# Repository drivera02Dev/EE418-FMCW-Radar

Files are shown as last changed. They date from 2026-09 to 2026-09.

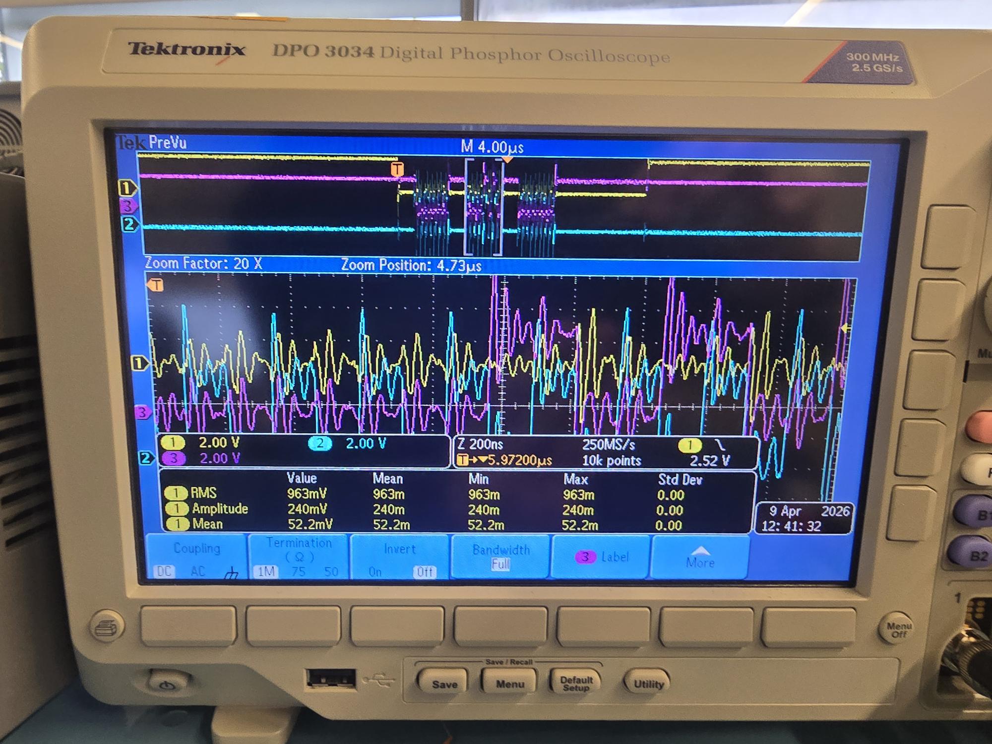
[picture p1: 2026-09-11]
SPI/Read_4.jpg

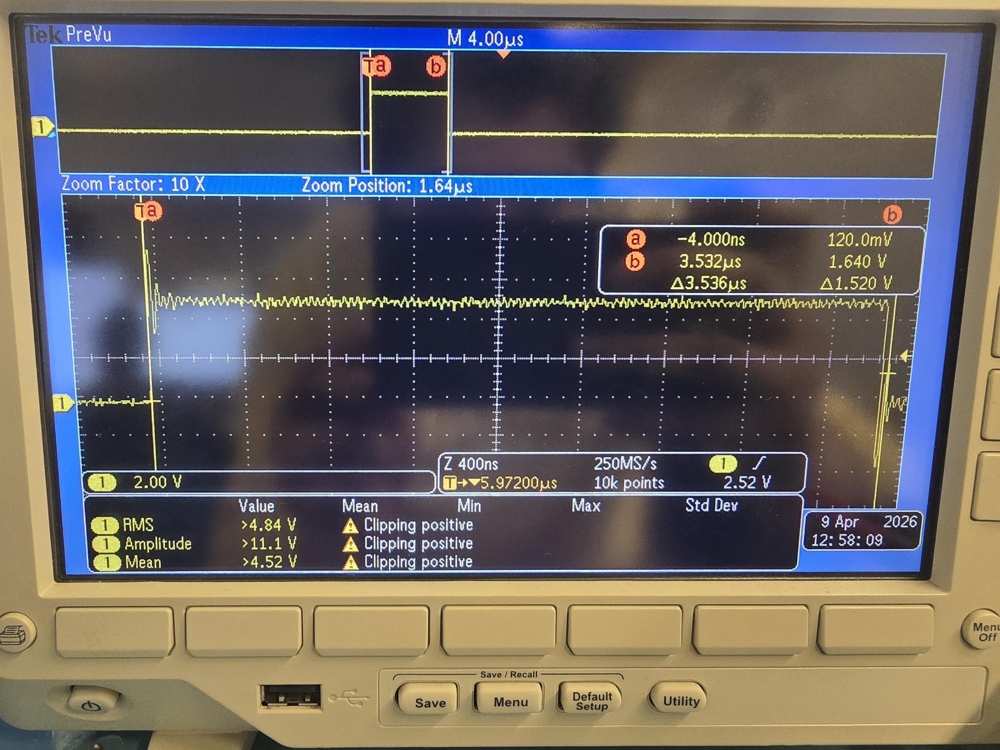
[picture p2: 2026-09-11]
SPI/04a_TxADV.jpg

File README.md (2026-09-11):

# FMCW Radar High Speed Measurement Systems

This project was a group effort and we each had our own sub teams within the team. 

Team
- Ryland Feist
- John Anderson
- Samuel Leto
- Diego Rivera
- Babar Ali
- Cole Dustin
- Luke Walsh

Groups
- Transmitter and Reciever boards
- VCO
- Antenna Design
- SPI

I worked with Cole to design the antenna, we ended up chosing a Vivaldi antenna for our geometry and tuned the antenna array in CST Studio Suite

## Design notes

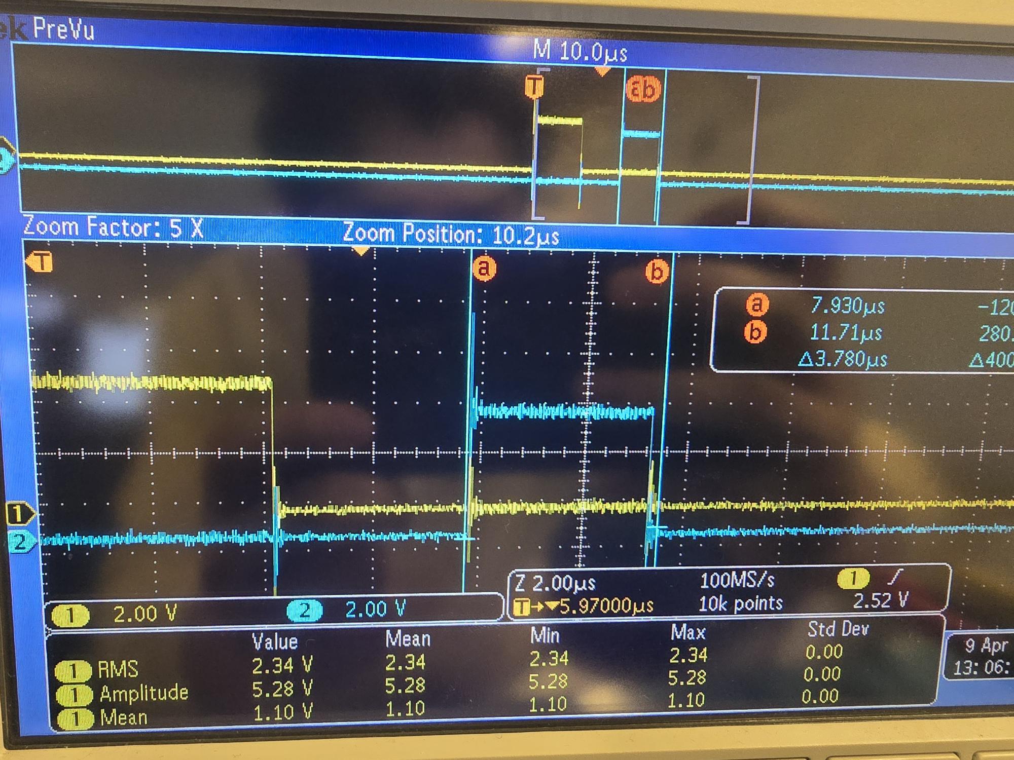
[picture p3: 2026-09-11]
SPI/Reset_2.jpg

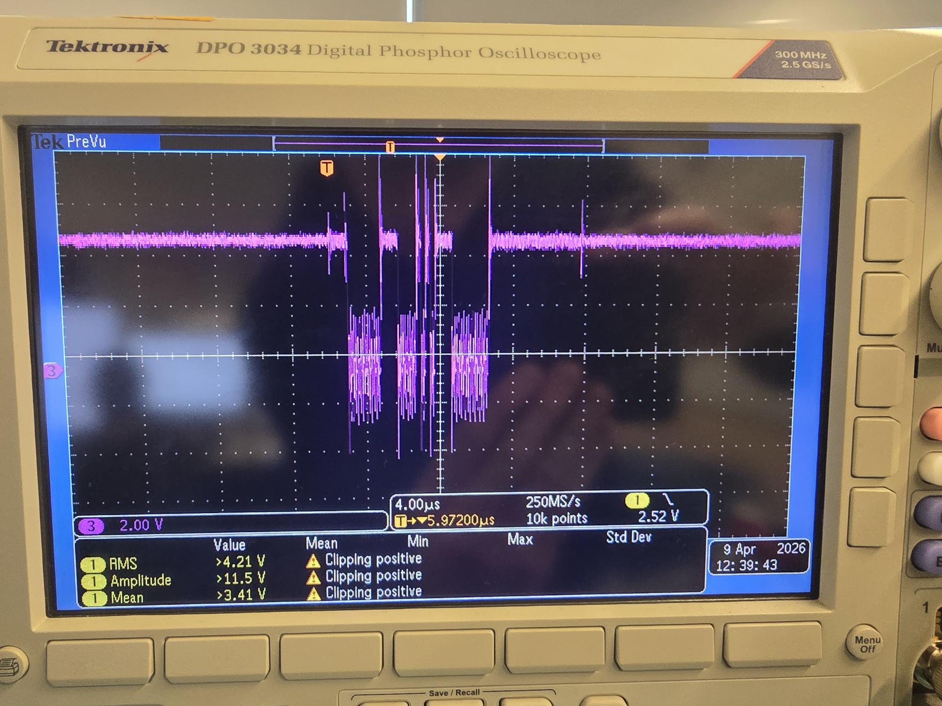
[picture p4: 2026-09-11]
SPI/Read_8.jpg

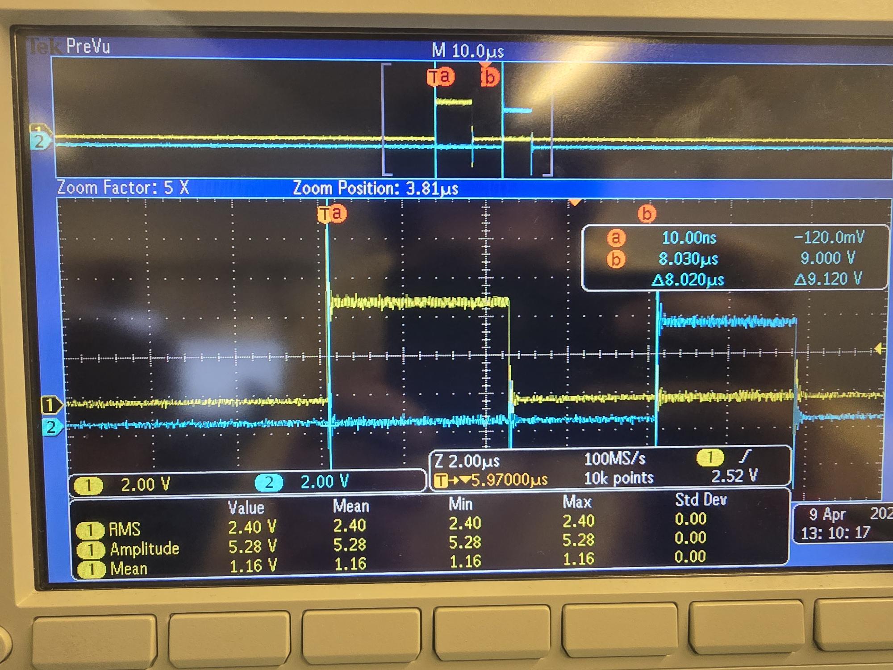
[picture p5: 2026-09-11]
SPI/Reset_5.jpg

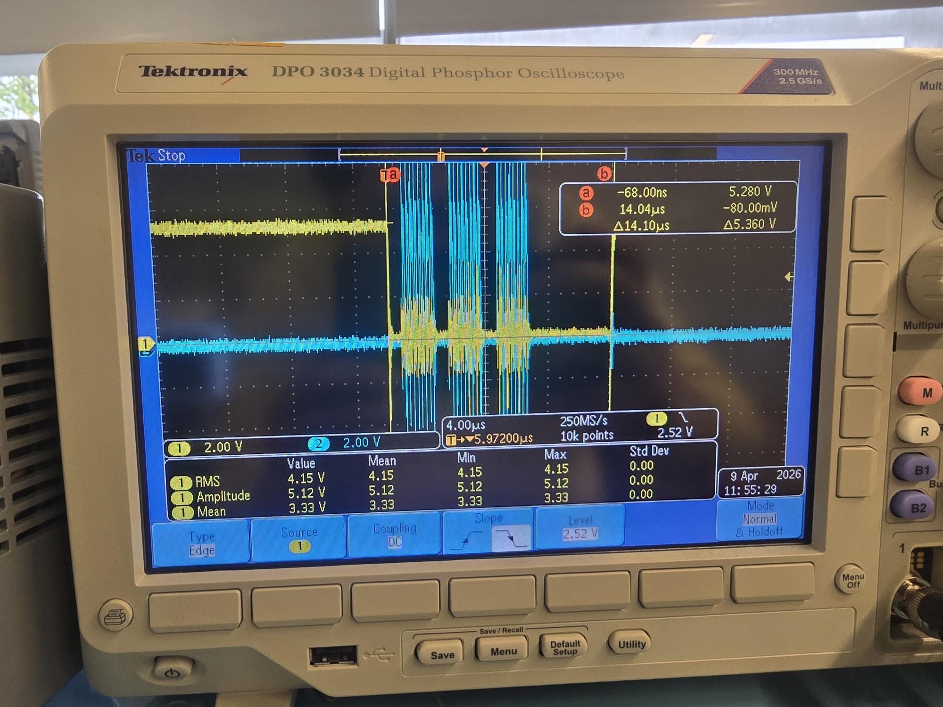
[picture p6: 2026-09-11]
SPI/shared image (6).jpg

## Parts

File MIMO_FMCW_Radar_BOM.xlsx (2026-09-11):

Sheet: VCO
Manufacturer Part Number: | Manufacturer: | Quantity: | Designator(s): | Price: | Total Cost: | Description:
RP0603BRD0725RL | Yageo | 3 | N/A | $0.22 | $0.66 | RES 25 OHM 0.1% 1/10W 0603
KDV06DR220ET | Ohmite | 2 | N/A | $0.22 | $0.44 | RES 0.22 OHM 0.5% 1/5W 0603
RN73H1JTTD62R6B50 | KOA Speer | 4 | N/A | $0.21 | $0.84 | RES 62.6 OHM 0.1% 1/10W 0603
LM7805CT/NOPB | Texas Instruments | 1 | N/A | $1.80 | $1.80 | IC REG LINEAR 5V 1.5A TO220-3
C0402C102K5RACTU | KEMET | 1 | N/A | $0.08 | $0.08 | 1000 pF ±10% 50V Ceramic Capacitor X7R 0402 (1005 Metric)
GRT155R61A224KE01D | Murata | 1 | N/A | $0.10 | $0.10 | CAP CER 0.22UF 10V X5R 0402
KGM05AR51A474KH | Kyocera | 1 | N/A | $0.52 | $0.52 | 0.47 µF ±10% 10V Ceramic Capacitor X5R 0402 (1005 Metric)
142-1701-831 | Cinch Connectivity Solutions | 3 | N/A | $13.04 | $39.12 | RF SMA Connector, 1 Contact(s), Female, Board Mount, Surface Mount Terminal, Locking, Jack
HMC586LC4BTR | Analog Devices | 1 | N/A | 273.23 | $273.23 | IC VCO BUFFER AMP 8 GHZ
 |  |  |  |  | $316.13

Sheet: Receiver
Manufacturer Part Number: | Manufacturer: | Quantity: | Designator(s): | Price: | Total Cost: | Description:
UMK107AB7105KA-T | TAIYO YUDEN | 8 | C1, C2, C9, C11, C18, C19, C20, C22 | $0.08 | $0.64 | Ceramic Capacitor, Multilayer, Ceramic, 50V, 10% +Tol, 10% -Tol, X7R, 15% TC, 1uF, Surface Mount, 0603
CGA3E2X7R1H103K080AA | TDK | 3 | C3, C5, C7 | $0.10 | $0.30 | CGA Series 0603 10 nF 50 V ±10 % Tolerance X7R SMT Multilayer Ceramic Capacitor
C0603C101J5GACTU | Yageo Group | 3 | C4, C6, C8 | $0.10 | $0.30 | Multilayer Ceramic Capacitors MLCC – SMD/SMT; KEMET; C0603C101J5GACTU; 100 pF; 0603; 50 V; 50 V
CGA3E2X7R1H104K080AA | TDK | 9 | C10, C12, C13, C14, C15, C16, C23, C24, C25 | $0.10 | $0.90 | Ceramic Capacitor, Multilayer, Ceramic, 50V, 10% +Tol, 10% -Tol, X7R, 15% TC, 0.1uF, Surface Mount, 0603
GRM21BR61E106MA73L | Murata | 2 | C17, C21 | $0.15 | $0.30 | Ceramic Capacitor, Multilayer, Ceramic, 25V, 20% +Tol, 20% -Tol, X5R, 15% TC, 10uF, Surface Mount, 0805
LTST-C190KRKT | Lite-On | 1 | D1 | $0.14 | $0.14 | Red, Single Color LED, Red, Water Clear
PMEG2010BER,115 | Nexperia | 1 | D2 | $0.37 | $0.37 | PMEG2010 Series 20 V 1 A SMT Low VF MEGA Schottky Barrier Rectifier - SOD-123W
BLM18AG601SN1D | Murata | 1 | FB1 | $0.10 | $0.10 | Ferrite Beads Multi-Layer 600Ohm 25% 100MHz 500mA 380mOhm DCR 0603 Automotive Paper T/R
142-1701-831 | Cinch Connectivity Solutions | 5 | J2, J3, J4, J5, J6 | $13.04 | $65.20 | RF SMA Connector, 1 Contact(s), Female, Board Mount, Surface Mount Terminal, Locking, Jack
RG1608P-204-B-T5 | Susumu | 1 | R1 | $0.10 | $0.10 | Res Thin Film 0603 200K Ohm 0.1% 0.1W(1/10W) ±25ppm/C Sulfur Resistant Pad SMD Automotive T/R
CAY16-22R0F4LF | Bourns | 1 | R2 | $0.10 | $0.10 | Res Thick Film Array 22 Ohm 1% 0.25W(1/4W) ±200ppm/C ISOL 8-Pin 1206(4 X 0603) Convex SMD T/R
RC0603FR-0710KL | Yageo Group | 2 | R3, R4 | $0.10 | $0.20 | Fixed Resistor, Metal Glaze/thick Film, 0.1W, 10000ohm, 75V, 1% +/-Tol, 100ppm/Cel, Surface Mount, 0603
RMCF0603FT150R | Stackpole Electronics | 1 | R5 | $0.10 | $0.10 | 150 Ohm, Res Thick Film 0603 1% 0.1W ±100ppm/°C Molded SMD Paper T/R
MTY2-243+ | Mini-Circuits | 4 | T1, T2, T3, T4 | $20.63 | $82.52 | RF Transformer, 10000MHz Min, 24000MHz Max
ADAR2004ACCZ | Analog Devices | 1 | U1 | $146.37 | $146.37 | 10 GHz to 40 GHz, 4-Channel Rx Mixer with 4× LO Multiplier/Filter
SN74LVC8T245DGVR | Texas Instruments | 1 | U2 | $1.57 | $1.57 | IC BUS TRANSCVR 8BIT 24TVSOP / Voltage Level Translator 8-CH Bidirectional 24-Pin TVSOP T/R
74AXP2T45DCH | Nexperia | 2 | U3, U5 | $0.62 | $1.24 | Dual Supply Level Translator 2-bit Bidirectional 0.95V to 5.5V 8-Pin VSSOP
ADP7156ARDZ-2.5-R7 | Analog Devices | 1 | U4 | $8.42 | $8.42 | LDO Regulator Pos 2.5V 1.2A 8-Pin SOIC N EP T/R
 |  |  |  |  | $308.87

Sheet: Antenna
Manufacturer Part Number: | Manufacturer: | Quantity: | Designator(s): | Price: | Total Cost: | Description:
142-0761-831 | Cinch Connectivity Solutions | 10 | N/A | $12.33 | $123.30 | SMA Connector
 |  |  |  |  | $123.30

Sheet: Transmitter
Manufacturer Part Number: | Manufacturer: | Quantity: | Designator(s): | Price: | Total Cost: | Description:
UMK107AB7105KA-T | TAIYO YUDEN | 8 | C1, C2, C11, C13, C19, C22, C23, C24 | $0.08 | $0.64 | Ceramic Capacitor, Multilayer, Ceramic, 50V, 10% +Tol, 10% -Tol, X7R, 15% TC, 1uF, Surface Mount, 0603
CGA3E2X7R1H103K080AA | TDK | 4 | C3, C5, C7, C9 | $0.10 | $0.40 | CGA Series 0603 10 nF 50 V ±10 % Tolerance X7R SMT Multilayer Ceramic Capacitor
C0603C101J5GACTU | Yageo Group | 4 | C4, C6, C8, C10 | $0.10 | $0.40 | Multilayer Ceramic Capacitors MLCC – SMD/SMT; KEMET; C0603C101J5GACTU; 100 pF; 0603; 50 V; 50 V
CGA3E2X7R1H104K080AA | TDK | 9 | C12, C14, C15, C16, C17, C18, C20, C26, C27 | $0.10 | $0.90 | Ceramic Capacitor, Multilayer, Ceramic, 50V, 10% +Tol, 10% -Tol, X7R, 15% TC, 0.1uF, Surface Mount, 0603
GRM21BR61E106MA73L | Murata | 2 | C21, C25 | $0.15 | $0.30 | Ceramic Capacitor, Multilayer, Ceramic, 25V, 20% +Tol, 20% -Tol, X5R, 15% TC, 10uF, Surface Mount, 0805
LTST-C190KRKT | Lite-On | 1 | D1 | $0.14 | $0.14 | Red, Single Color LED, Red, Water Clear
PMEG2010BER,115 | Nexperia | 1 | D2 | $0.37 | $0.37 | PMEG2010 Series 20 V 1 A SMT Low VF MEGA Schottky Barrier Rectifier - SOD-123W
BLM18AG601SN1D | Murata | 1 | FB1 | $0.10 | $0.10 | Ferrite Beads Multi-Layer 600Ohm 25% 100MHz 500mA 380mOhm DCR 0603 Automotive Paper T/R
142-1701-831 | Cinch Connectivity Solutions | 5 | J2, J3, J4, J5, J6 | $13.04 | $65.20 | RF SMA Connector, 1 Contact(s), Female, Board Mount, Surface Mount Terminal, Locking, Jack
RG1608P-204-B-T5 | Susumu | 1 | R1 | $0.10 | $0.10 | Res Thin Film 0603 200K Ohm 0.1% 0.1W(1/10W) ±25ppm/C Sulfur Resistant Pad SMD Automotive T/R
CAY16-22R0F4LF | Bourns | 1 | R2 | $0.10 | $0.10 | Res Thick Film Array 22 Ohm 1% 0.25W(1/4W) ±200ppm/C ISOL 8-Pin 1206(4 X 0603) Convex SMD T/R
RC0603FR-0710KL | Yageo Group | 2 | R3, R5 | $0.10 | $0.20 | Fixed Resistor, Metal Glaze/thick Film, 0.1W, 10000ohm, 75V, 1% +/-Tol, 100ppm/Cel, Surface Mount, 0603
RMCF0603FT150R | Stackpole Electronics | 1 | R4 | $0.10 | $0.10 | 150 Ohm, Res Thick Film 0603 1% 0.1W ±100ppm/°C Molded SMD Paper T/R
MTY2-243+ | Mini-Circuits | 4 | T1, T2, T3, T4 | $20.63 | $82.52 | RF Transformer, 10000MHz Min, 24000MHz Max
ADAR2001ACCZ | Analog Devices | 1 | U1 | $137.82 | $137.82 | Active RF Multipliers x4 10GHz to 40GHz-OUT 40-Pin LGA EP Tray
SN74LVC8T245DGVR | Texas Instruments | 1 | U2 | $1.57 | $1.57 | IC BUS TRANSCVR 8BIT 24TVSOP / Voltage Level Translator 8-CH Bidirectional 24-Pin TVSOP T/R
74AXP2T45DCH | Nexperia | 2 | U3, U5 | $0.62 | $1.24 | Dual Supply Level Translator 2-bit Bidirectional 0.95V to 5.5V 8-Pin VSSOP
ADP7156ARDZ-2.5-R7 | Analog Devices | 1 | U4 | $8.42 | $8.42 | LDO Regulator Pos 2.5V 1.2A 8-Pin SOIC N EP T/R
 |  |  |  |  | $300.52

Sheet: Order
Manufacturer Part Number: | Manufacturer: | Quantity: | Price: | Line Cost: | DigiKey Part Number:
UMK107AB7105KA-T | TAIYO YUDEN | 50 | $0.0290 | $1.45 | 587-3247-1-ND
CGA3E2X7R1H103K080AA | TDK | 50 | $0.0246 | $1.23 | 445-5662-1-ND
C0603C101J5GACTU | Yageo Group | 50 | $0.0356 | $1.78 | 399-C0603C101J5GACTUCT-ND
CGA3E2X7R1H104K080AA | TDK | 50 | $0.0302 | $1.51 | 445-5666-1-ND
GRM21BR61E106MA73L | Murata | 10 | $0.0870 | $0.87 | 490-10748-1-ND
LTST-C190KRKT | Lite-On | 10 | $0.0980 | $0.98 | 160-1436-1-ND
PMEG2010BER,115 | Nexperia | 5 | $0.3700 | $1.85 | 1727-5191-1-ND
BLM18AG601SN1D | Murata | 10 | $0.0560 | $0.56 | 490-1014-1-ND
142-1701-831 | Cinch Connectivity Solutions | 16 | $11.0780 | $177.25 | J10163-ND
RG1608P-204-B-T5 | Susumu | 10 | $0.0810 | $0.81 | RG16P200KBCT-ND
CAY16-22R0F4LF | Bourns | 10 | $0.0410 | $0.41 | CAY16-22R0F4LFCT-ND
RC0603FR-0710KL | Yageo Group | 50 | $0.0056 | $0.28 | 311-10.0KHRCT-ND
RMCF0603FT150R | Stackpole Electronics | 25 | $0.0056 | $0.14 | RMCF0603FT150RCT-ND
MTY2-243+ | Mini-Circuits | 10 | $20.6300 | $206.30 | 3157-MTY2-243+-ND
SN74LVC8T245DGVR | Texas Instruments | 3 | $1.5700 | $4.71 | 296-19287-1-ND
74AXP2T45DCH | Nexperia | 6 | $0.6200 | $3.72 | 1727-74AXP2T45DCHCT-ND
ADP7156ARDZ-2.5-R7 | Analog Devices | 2 | $8.4200 | $16.84 | 505-ADP7156ARDZ-2.5-R7CT-ND
142-0761-831 | Cinch Connectivity Solutions | 10 | $10.4780 | $104.78 | J804-ND
RP0603BRD0725RL | Yageo | 10 | $0.0810 | $0.81 | 13-RP0603BRD0725RLCT-ND
CRCW0603220RFKEA | Vishay Dale | 10 | $0.0300 | $0.30 | 541-220HCT-ND
RN73H1JTTD62R6B50 | KOA Speer | 10 | $0.1720 | $1.72 | 2019-RN73H1JTTD62R6B50CT-ND
LM7805CT/NOPB | Texas Instruments | 2 | $1.8000 | $3.60 | 296-47192-ND
C0402C102K5RACTU | KEMET | 10 | $0.0040 | $0.04 | 399-C0402C102K5RACTUCT-ND
GRT155R61A224KE01D | Murata | 10 | $0.0330 | $0.33 | 490-GRT155R61A224KE01DCT-ND
KGM05AR51A474KH | Kyocera | 10 | $0.3150 | $3.15 | 478-KGM05AR51A474KHCT-ND
 |  |  |  | $535.42

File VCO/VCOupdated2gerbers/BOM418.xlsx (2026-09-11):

Componet Number: | Price: | Amount:
RP0603BRD0725RL | $0.22 | 3
KDV06DR220ET | $0.22 | 2
RN73H1JTTD62R6B50 | $0.21 | 4
LM7805CT/NOPB | $1.80 | 1
C0402C102K5RACTU | $0.08 | 1
GXT155R61A224KE01D | $0.23 | 1
KGM05AR71A474KH | $0.64 | 1

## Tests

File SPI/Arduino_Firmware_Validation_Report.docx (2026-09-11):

Arduino Firmware Bench Validation Report

FMCW MIMO Radar Controller — SPI and State-Machine Pulse Verification

Test date: 9 April 2026

# 1. Overview

This report documents bench-level validation of the Arduino firmware (radar_arduino_controller.ino) that controls the ADAR2001 transmit beamformer and ADAR2004 receive beamformer for the 16–24 GHz FMCW MIMO radar. The objective was to verify the firmware's SPI master and state-machine control pulses on the bench, prior to connecting the actual ADAR ICs and TXB0108 level shifter.

Validation was carried out at the Arduino digital I/O level (5 V logic) using only an oscilloscope and the Arduino Serial Monitor. No level shifter or ADAR boards were required for the tests in this report; the final end-to-end SPI test (scratchpad readback through the actual ADAR) is reserved for a follow-up session once the level shifter and ADAR boards are available.

## 2. Equipment

Item | Description
Microcontroller | Elegoo UNO R3 (Arduino Uno R3 compatible)
Firmware | radar_arduino_controller.ino, 24-bit SPI @ 4 MHz, Mode 0, MSB first
Oscilloscope | Tektronix DPO 3034 Digital Phosphor Oscilloscope (300 MHz, 2.5 GS/s, 4 channels)
Probes | Standard 10× passive probes (CH1–CH3)
Host | Laptop running Arduino IDE Serial Monitor at 115200 baud
Level shifter | TXB0108 (planned, NOT used in this test)
Target ICs | ADAR2001 / ADAR2004 (planned, NOT used in this test)

## 3. Pin Map Under Test

Arduino Pin | Signal | ADAR equivalent | Tested in
D13 | SCK | SCLK (ADAR2001 pin 12 / ADAR2004 pin 27) | Tests 1–3
D11 | MOSI | SDIO (ADAR2001 pin 13 / ADAR2004 pin 26) | Test 3
D12 | MISO | SDO (ADAR2001 pin 15 / ADAR2004 pin 24) | Not probed (no chip connected)
D10 | CS_TX | CS (ADAR2001 pin 14) | Tests 1–3
D9 | CS_RX | CS (ADAR2004 pin 25) | Test 4 (isolation)
D8 | TxADV | TxADV (ADAR2001 pin 8) | Test 4
D7 | TxRST | TxRST (ADAR2001 pin 9) | Test 4
D6 | MADV | MADV (ADAR2001 pin 10) | Test 4
D5 | MRST | MRST (ADAR2001 pin 11) | Test 4

## 4. Common Oscilloscope Settings

CH1 (yellow): 2.00 V/div, DC coupling, 10× probe attenuation.

CH2 (blue): 2.00 V/div, DC coupling, 10× probe attenuation.

CH3 (magenta, Test 3 only): 2.00 V/div, DC coupling, 10× probe attenuation.

Trigger: Edge, Mode = Normal, Single Sequence, Level ≈ 2.52 V (mid-supply).

Sample rate: 250 MS/s @ 4 µs/div, 100 MS/s @ 10 µs/div, record length 10 k points.

# Test 1 — 24-bit SPI Frame Length Verification

## Objective

Confirm that one SPI write transaction produced by the firmware contains exactly 24 SCK pulses while CS is held low. This proves the SPI frame format is [R/W (1 bit) | ADDR (15 bits) | DATA (8 bits)] as required by the ADAR2001/ADAR2004 datasheets, and rules out the previously-fixed 16-bit-frame regression.

## Procedure

1. CH1 probe → D10 (CS_TX); CH2 probe → D13 (SCK).

2. Trigger source = CH1, slope = Falling, level = 2.52 V.

3. Time base = 4 µs/div; Single Sequence acquisition.

4. Sent the command "W 00A A5" via Serial Monitor (write 0xA5 to TX register 0x00A).

5. Used cursors to measure CS-low duration; used 5× Wave Inspector zoom to verify the byte structure.

## Results

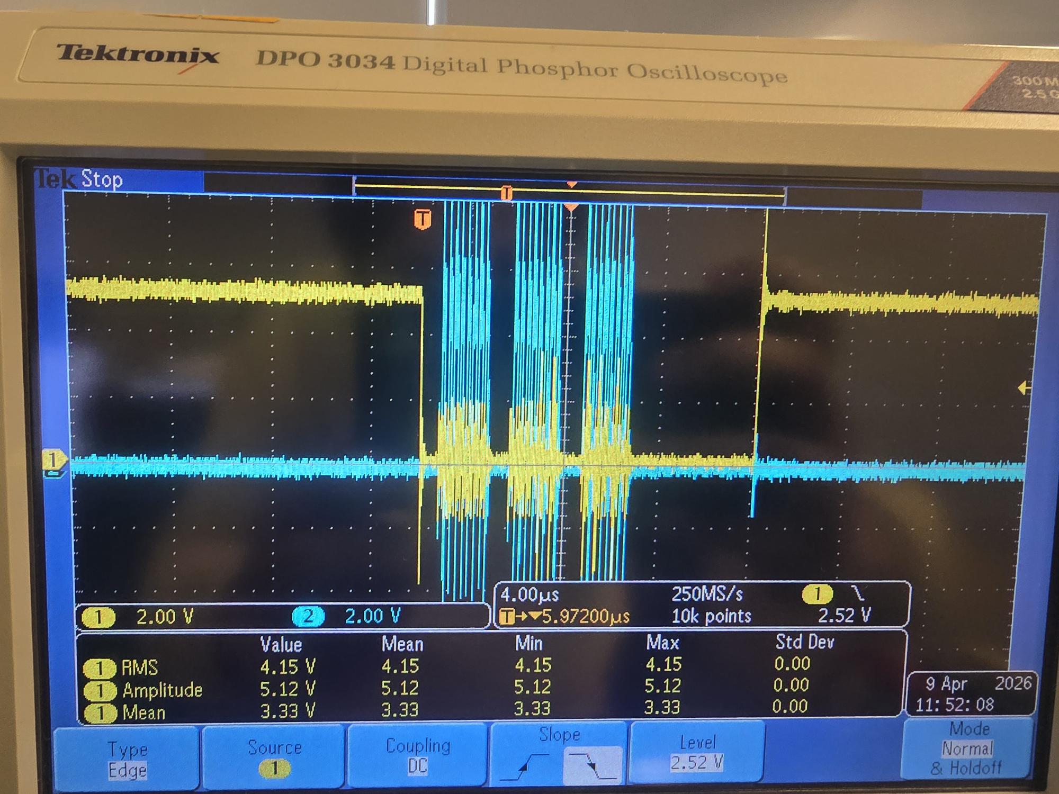
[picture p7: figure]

Figure 1.1 — Full SPI write transaction. Yellow (CH1) = CS_TX; blue (CH2) = SCK. Cursor measurement: Δ = 14.10 µs CS-low duration. Signal amplitude 5.12 V.

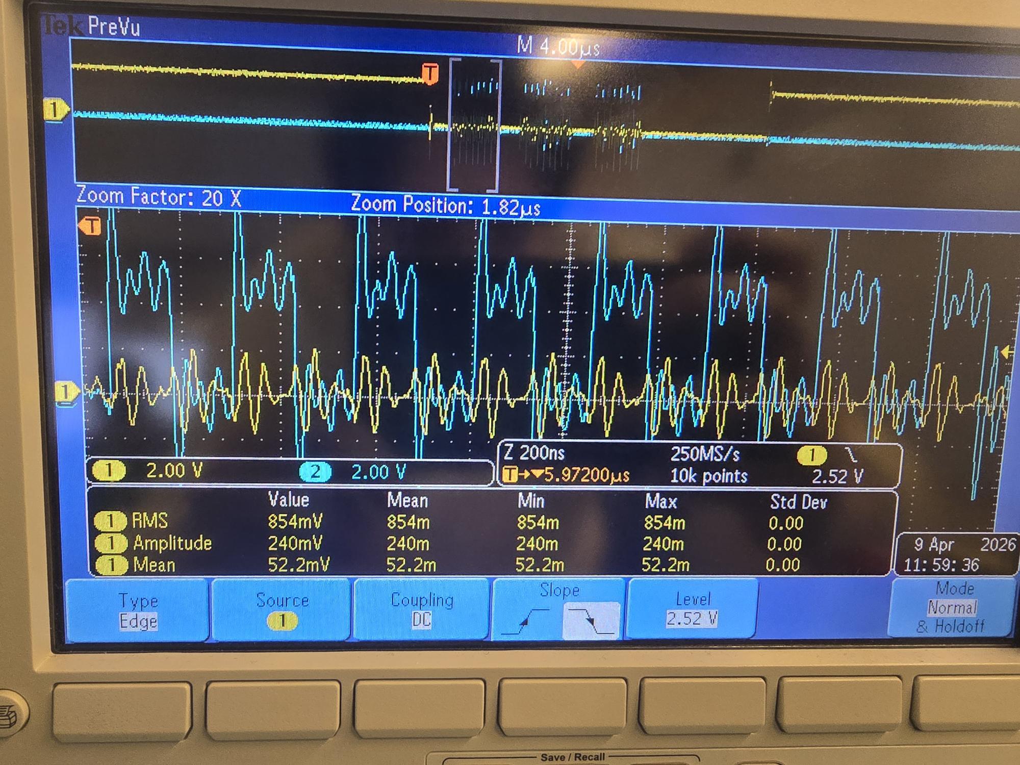
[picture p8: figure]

Figure 1.2 — 5× Wave Inspector zoom on the same transaction, clearly showing three distinct byte clusters of 8 SCK pulses each (total 24 clocks), separated by short inter-byte CPU gaps. This is the expected pattern for an Arduino Uno SPI driver issuing three sequential SPI.transfer() calls within one CS-low window.

## Analysis

CS-low duration of 14.10 µs is consistent with three byte clusters at 4 MHz SCK plus inter-byte CPU overhead from the Arduino SPI library. The 5× zoom confirms three distinct clusters of 8 SCK pulses, totalling 24 clocks per CS-low window. SCK idles low (CPOL = 0) before and after the transaction. Signal amplitude is a clean 5.12 V with sharp edges.

## Verdict

PASS — 24-bit SPI frame length verified.

# Test 2 — Upper Address Byte Handling

## Objective

Confirm that the firmware correctly handles a register address whose upper byte is non-zero. Address 0x100 has bit 8 set, exercising the upper-address-byte path that would be skipped if the firmware ever reverted to a 16-bit frame. The frame length must remain 24 bits regardless of address.

## Procedure

1. Same probe setup and scope configuration as Test 1.

2. Sent the command "W 100 FF" via Serial Monitor (write 0xFF to TX register 0x100).

3. Re-measured the CS-low duration with cursors.

## Results

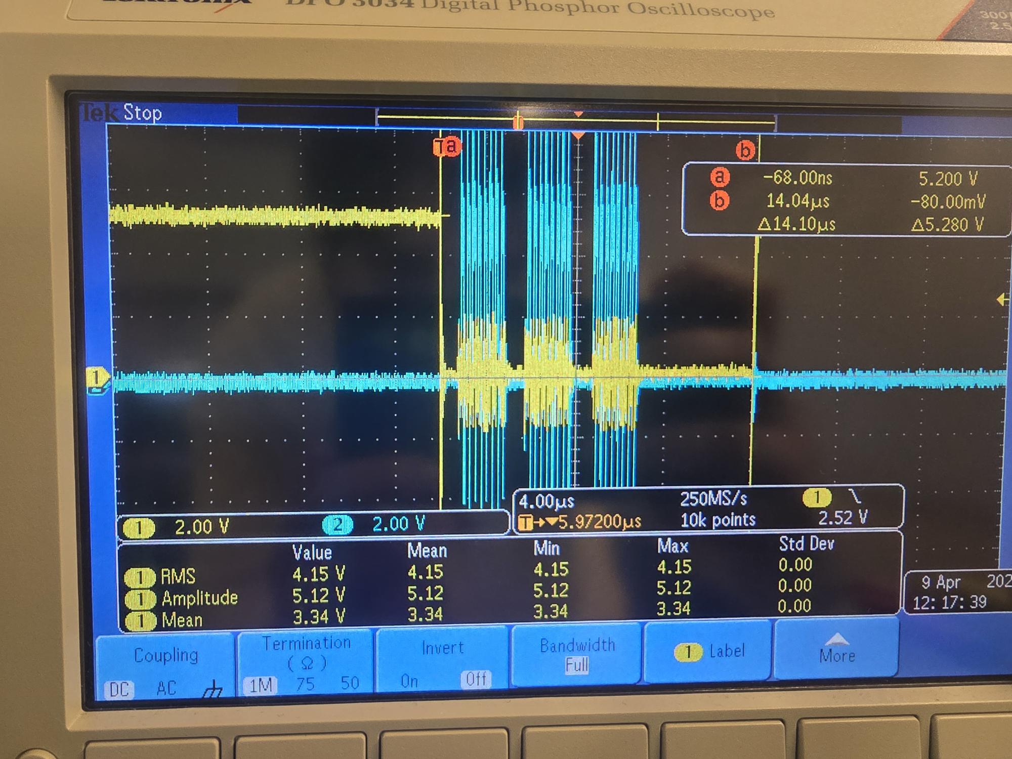
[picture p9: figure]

Figure 2.1 — SPI write to register 0x100 with data 0xFF. Cursor measurement: Δ = 14.10 µs (identical to Test 1). Three SCK byte clusters visible. Amplitude 5.12 V.

## Analysis

CS-low duration is identical to Test 1 (14.10 µs), confirming that the SPI frame length is independent of the address value. The three byte clusters and idle states match Test 1 exactly. The firmware correctly transmits all 24 bits regardless of which address bits are set.

## Verdict

PASS — upper address byte correctly handled.

# Test 3 — R/W Flag Bit Verification (MOSI)

## Objective

Confirm that the read/write flag (the MSB of the first byte transmitted on MOSI) is set correctly: 0 for write, 1 for read. This requires probing the MOSI line directly and comparing the first MOSI bit at the moment of the first SCK rising edge across a write and a read transaction.

## Procedure

1. Added CH3 probe on D11 (MOSI), CH3 = 2 V/div.

2. Reference capture: sent "W 00A A5" (write).

3. Read capture: sent "X 00A" (read from TX register 0x00A).

4. Compared MOSI behaviour during the first byte cluster of each capture.

## Results — Write Reference (W 00A A5)

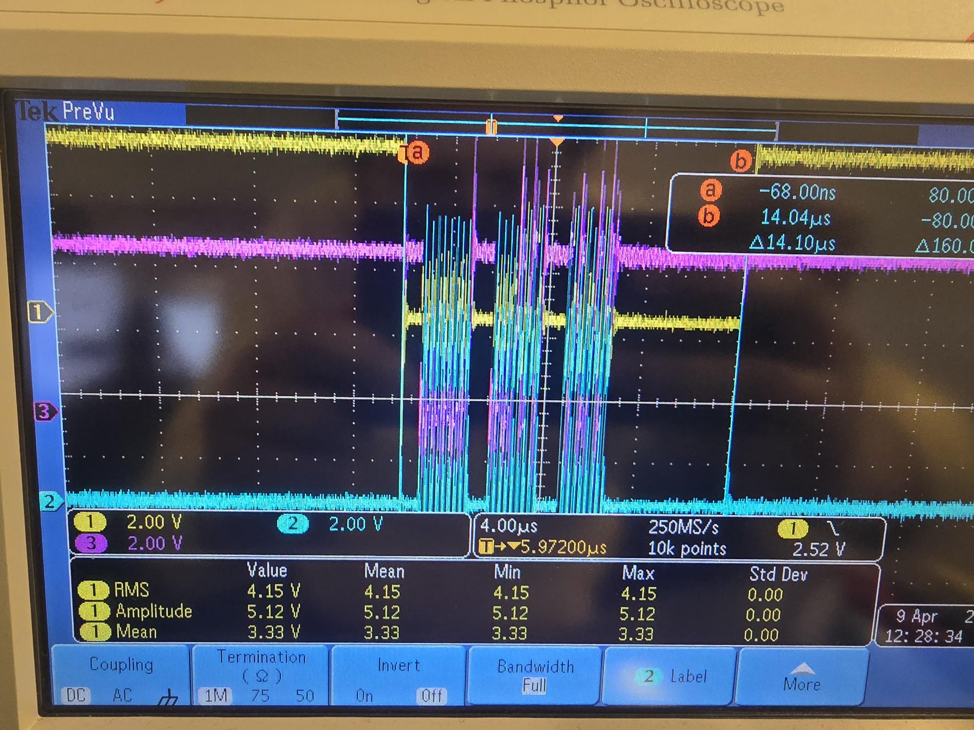
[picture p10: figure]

Figure 3.1 — Write reference, all three channels. Yellow = CS_TX, blue = SCK, magenta = MOSI. Cursor: Δ = 14.10 µs. The first byte (write flag + upper address) is 0x00, so MOSI stays LOW throughout the first byte cluster.

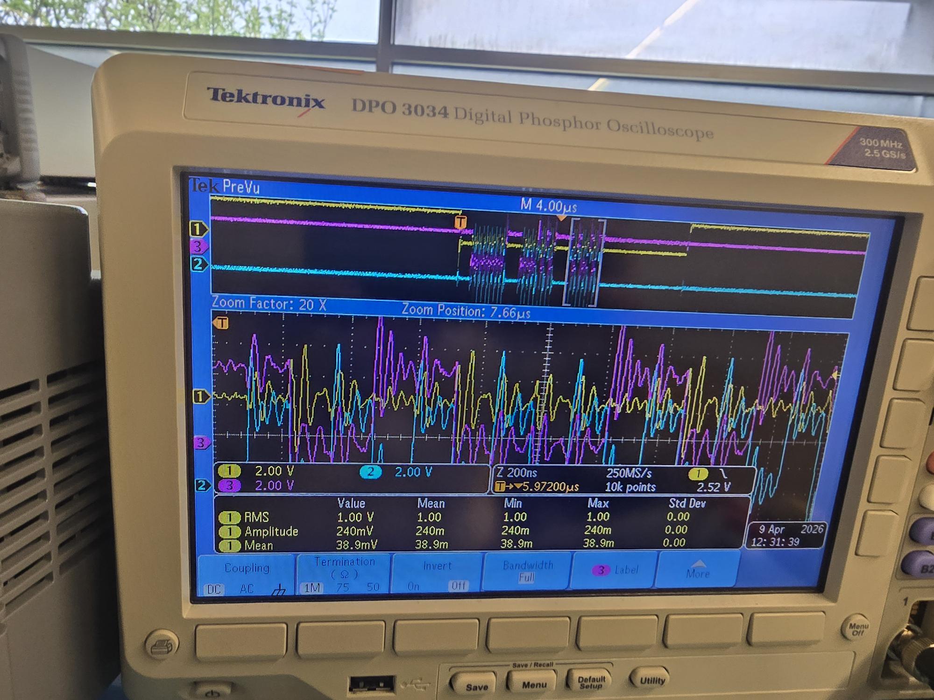
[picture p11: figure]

Figure 3.2 — Same write transaction, MOSI alone. The first byte cluster shows MOSI flat at 0 V (binary 00000000 = write flag 0 + upper address 0x00). The second cluster shows the lower address byte 0x0A (binary 00001010), and the third cluster shows the data byte 0xA5 (binary 10100101).

## Results — Read Capture (X 00A)

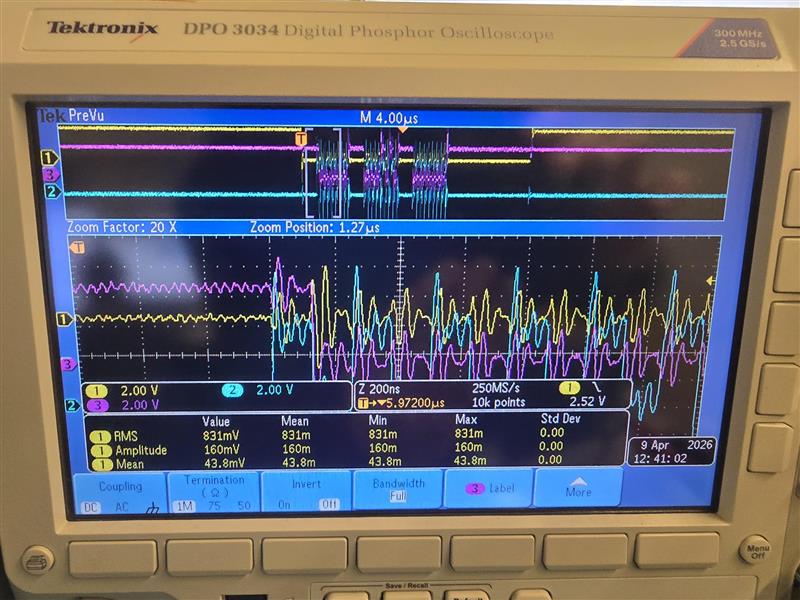
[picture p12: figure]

Figure 3.3 — Read transaction, all three channels. Same overall structure as the write (24-bit frame, 14.10 µs CS-low), but MOSI shows a HIGH bit at the start of the first byte cluster.


Figure 3.4 — Read transaction, MOSI alone. The first byte cluster begins with MOSI HIGH for one bit, then drops LOW for the remaining seven bits (binary 10000000 = read flag 1 + upper address 0x00). This is the diagnostic that proves the R/W flag bit is correctly placed.

## Analysis

Direct comparison of Figure 3.2 (write) and Figure 3.4 (read) shows the only meaningful difference: MOSI starts LOW on the write and HIGH on the read. This corresponds exactly to the firmware's spiRead() implementation, which sets the MSB of the first byte via "0x80 | ((addr >> 8) & 0x7F)". The MSB-first bit order is also confirmed by the fact that the flag is the very first bit clocked out on the first SCK rising edge.

## Verdict

PASS — R/W flag bit correctly placed; MSB-first bit order confirmed.

# Test 4 — State-Machine Control Pulses

## Objective

Verify that the four state-machine control pins (TxADV, MADV, TxRST, MRST) produce the correct pulse shapes when triggered by Serial Monitor commands, and that the reset sequence (R command) fires MRST before TxRST as required by the firmware specification.

## Procedure

1. CH3 disabled (not needed for this test).

2. For each pulse: moved CH1 probe to the relevant pin, set trigger source = CH1, slope = Rising, level ≈ 2.5 V.

3. Sent the corresponding Serial Monitor command and captured the resulting pulse with Single Sequence.

4. Used cursors to measure pulse width and (for the reset sequence) the inter-pulse delay.

5. Reset sequence: CH1 on D5 (MRST), CH2 on D7 (TxRST), trigger on CH1 rising; sent "R" command.

## Results — MADV Pulse (M command)

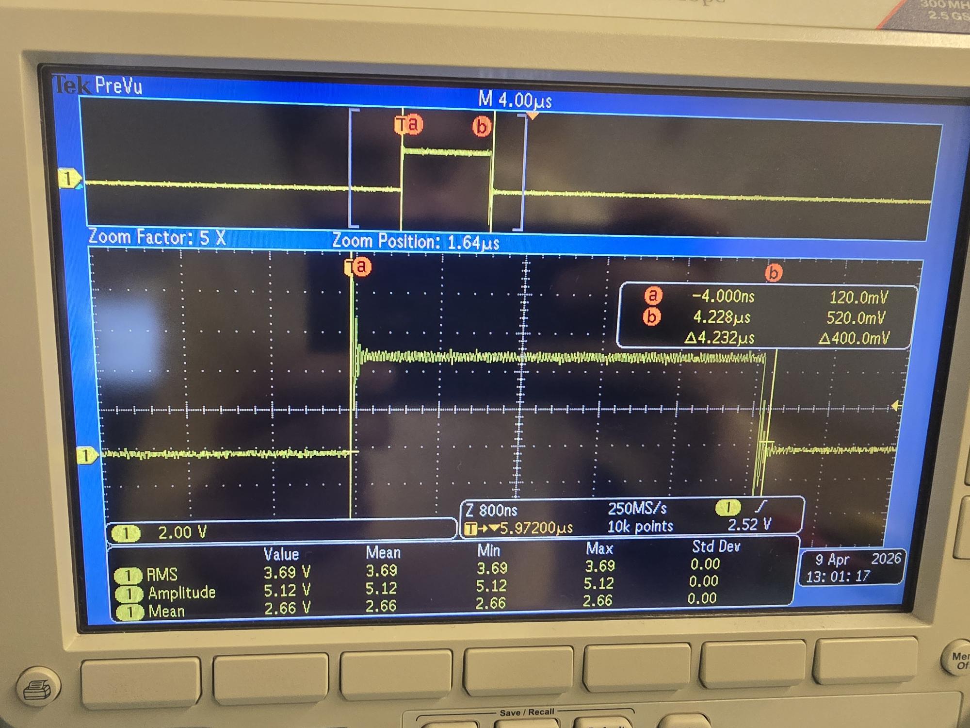
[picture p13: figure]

Figure 4.1 — MADV pulse on D6 in response to "M" command. Cursor measurement: Δ = 4.232 µs total pulse width. Amplitude 5.12 V. The TxADV pulse on D8 in response to "P" was verified by the same procedure and is functionally identical.

## Results — Reset Sequence (R command)

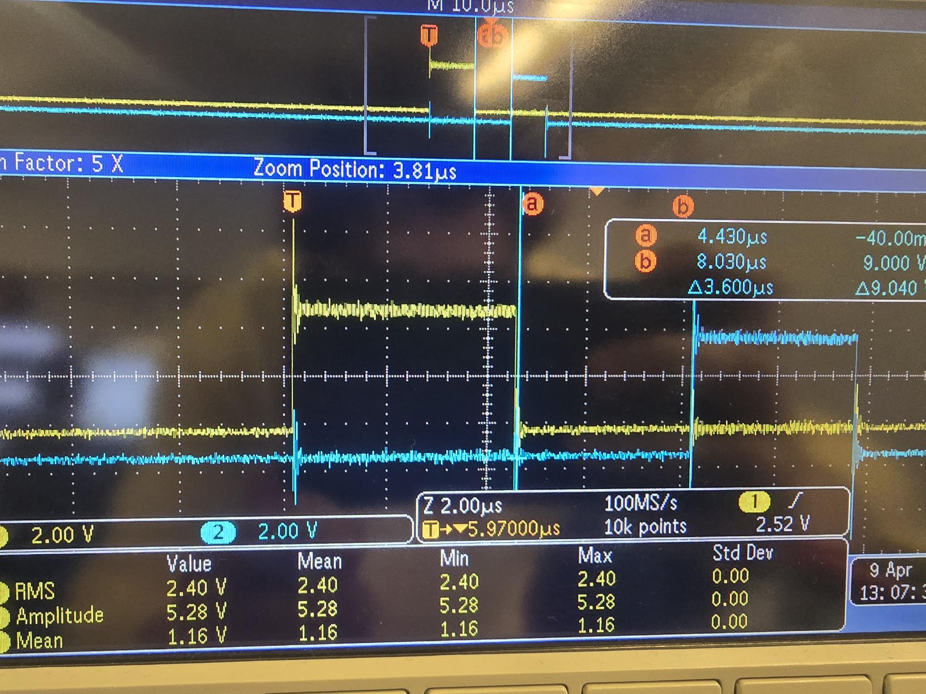
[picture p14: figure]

Figure 4.2 — Reset sequence in response to "R" command, 5× zoom. Yellow (CH1) = MRST on D5; blue (CH2) = TxRST on D7. Cursor measurement: Δ = 3.78 µs from MRST rising edge to TxRST rising edge. MRST fires first, TxRST fires second — correct order per firmware specification.


Figure 4.3 — Same reset sequence, additional capture. Inter-pulse delay measured at 4.52 µs. Variation between captures (3.6 µs to 8 µs across multiple runs) is normal Arduino Uno timing jitter from digitalWrite() and Serial command processing overhead. Order remains MRST → TxRST in every capture.

## Analysis

All four control pulses produce clean rectangular waveforms with full 5 V swing. Measured pulse widths (3–6 µs) exceed the firmware's nominal 1 µs by the expected digitalWrite() overhead on the Arduino Uno (~3–5 µs per call). All measured widths are well above the ADAR2001 datasheet minimum pulse width of 10 ns for state-machine inputs, so timing margin is excellent.

The reset sequence consistently fires MRST before TxRST in every capture, matching the firmware sequence "pulseMRST(); pulseTxRST();" in the case 'R' handler. Inter-pulse delay variation across captures (3.6–8.0 µs) reflects normal Arduino timing jitter and is acceptable for state-machine reset.

CS isolation between CS_TX and CS_RX was also confirmed during this test session: a "W 00A A5" command pulls CS_TX low while CS_RX remains high, and vice-versa for "w 00A 5A". An initial trigger configuration issue (trigger source left on CH1 while probing CH2) was identified and corrected by switching the trigger source to CH2 before sending the lowercase command — the firmware behaviour itself was correct.

## Verdict

PASS — all control pulses verified, reset sequence order correct.

# Summary

Test | Description | Key measurement | Result
1 | 24-bit SPI frame length | 24 SCK pulses; CS-low Δ = 14.10 µs | PASS
2 | Upper address byte (0x100) | CS-low Δ = 14.10 µs (identical to Test 1) | PASS
3 | R/W flag bit on MOSI | Write: MOSI LOW; Read: MOSI HIGH at first SCK edge | PASS
4 | Control pulses & reset order | MADV = 4.23 µs; MRST → TxRST order verified | PASS

## Items Validated

• 24-bit SPI frame format ([R/W | ADDR | DATA] = 1+15+8 bits)

• MSB-first bit order

• SPI Mode 0 (CPOL = 0, CPHA = 0)

• 4 MHz SCK frequency

• 5 V signal levels with clean edges (5.12 V measured amplitude)

• Independent address handling (0x00A and 0x100 both correct)

• R/W flag bit correctly placed for both write and read transactions

• Both CS_TX (D10) and CS_RX (D9) chip-select lines functional

• Chip-select isolation between TX and RX paths

• All four state-machine control pulses (TxADV, MADV, TxRST, MRST)

• Reset sequence fires MRST before TxRST in correct order

## Conclusion

The Arduino firmware (radar_arduino_controller.ino) is fully validated at the digital I/O boundary. All SPI signals and state-machine control pulses produce the correct waveforms, voltage levels, and timing. The firmware is ready to drive the ADAR2001 and ADAR2004 ICs once the TXB0108 level shifter and ADAR boards are wired up.

## Next Step (Pending Hardware)

The remaining validation step is the end-to-end SPI scratchpad readback test through the actual ADAR ICs. This test sends "V" via Serial Monitor; the firmware writes 0xA5 to register 0x00A on the ADAR2001, reads it back, then repeats with 0x5A on the ADAR2004. A successful "OK VERIFY" response will prove the full SPI path including the TXB0108 level shifter (5 V ↔ 1.8 V), grounds, and chip-select routing. This test requires the level shifter and ADAR boards, which are not yet wired up.

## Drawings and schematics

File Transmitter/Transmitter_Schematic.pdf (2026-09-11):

# VLogic 1 2

## ______Level Shifter______

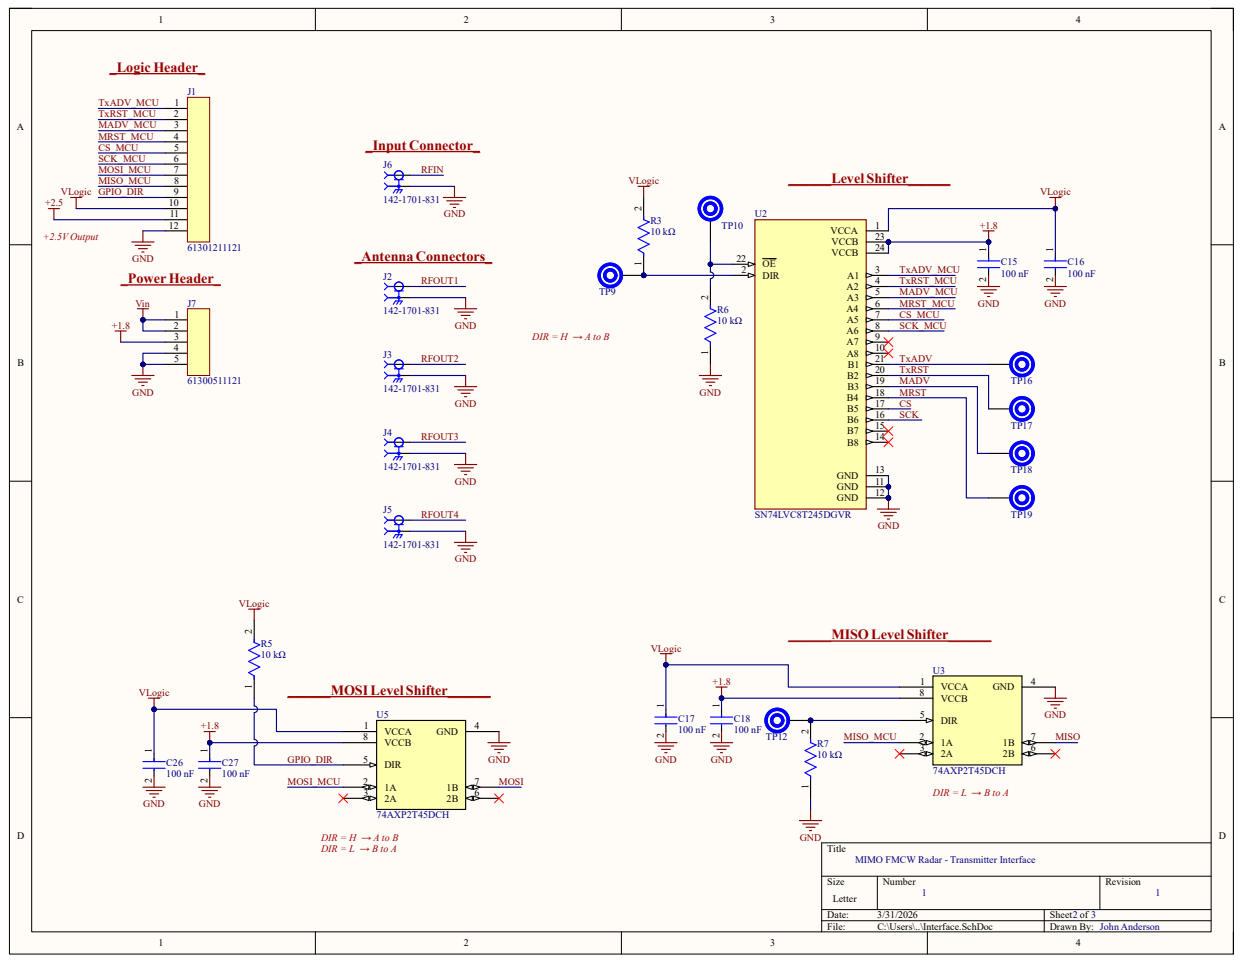
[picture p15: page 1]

GND
Title
MIMO FMCW Radar - Transmitter Interface

_+1.8 Filtering_ | __Input Filtering__

## _Power Indicator_

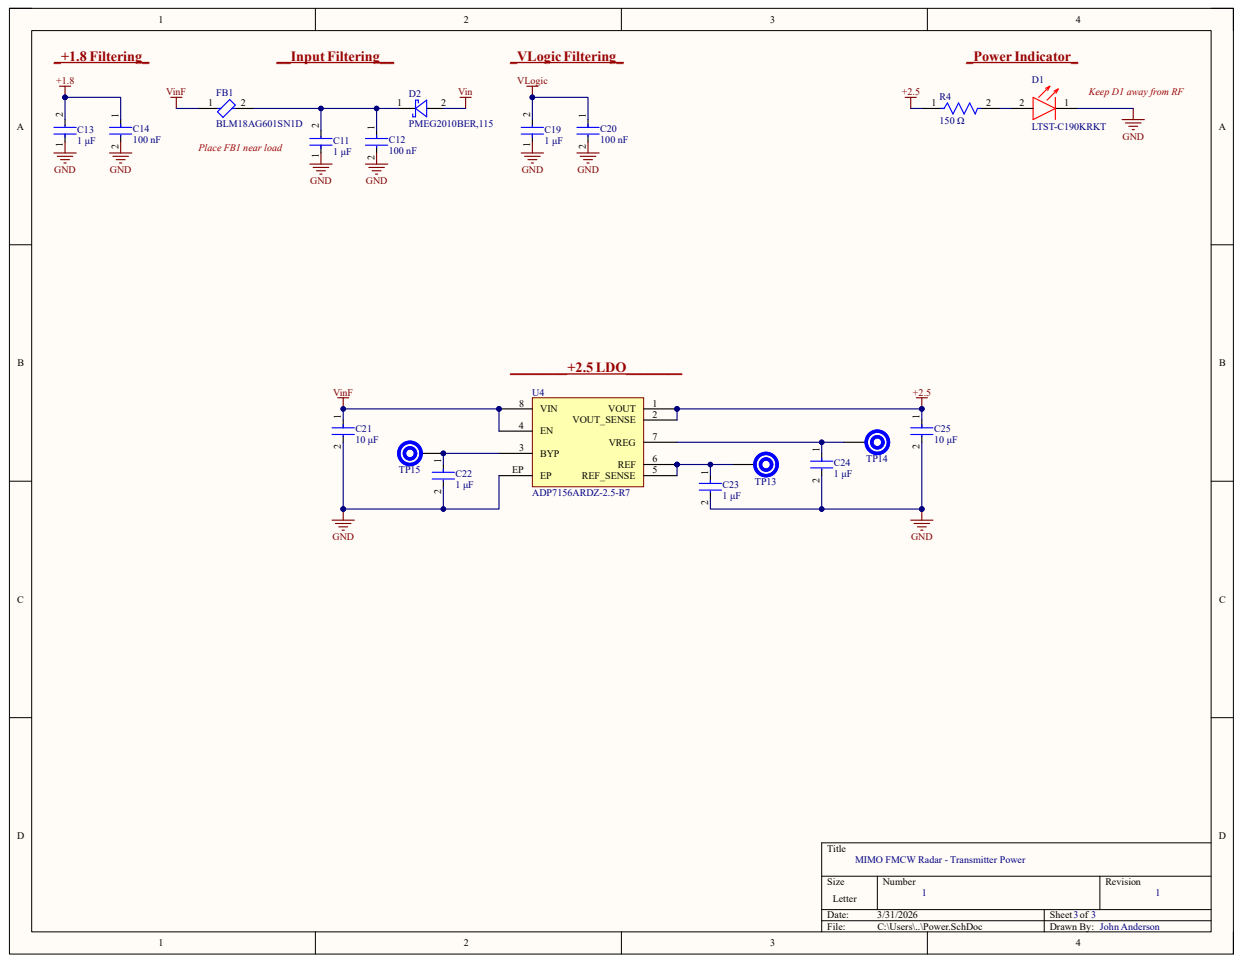
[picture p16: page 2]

Keep D1 away from RF

Title
MIMO FMCW Radar - Transmitter Power

## _+2.5V Bulk_

## _VPOS1_

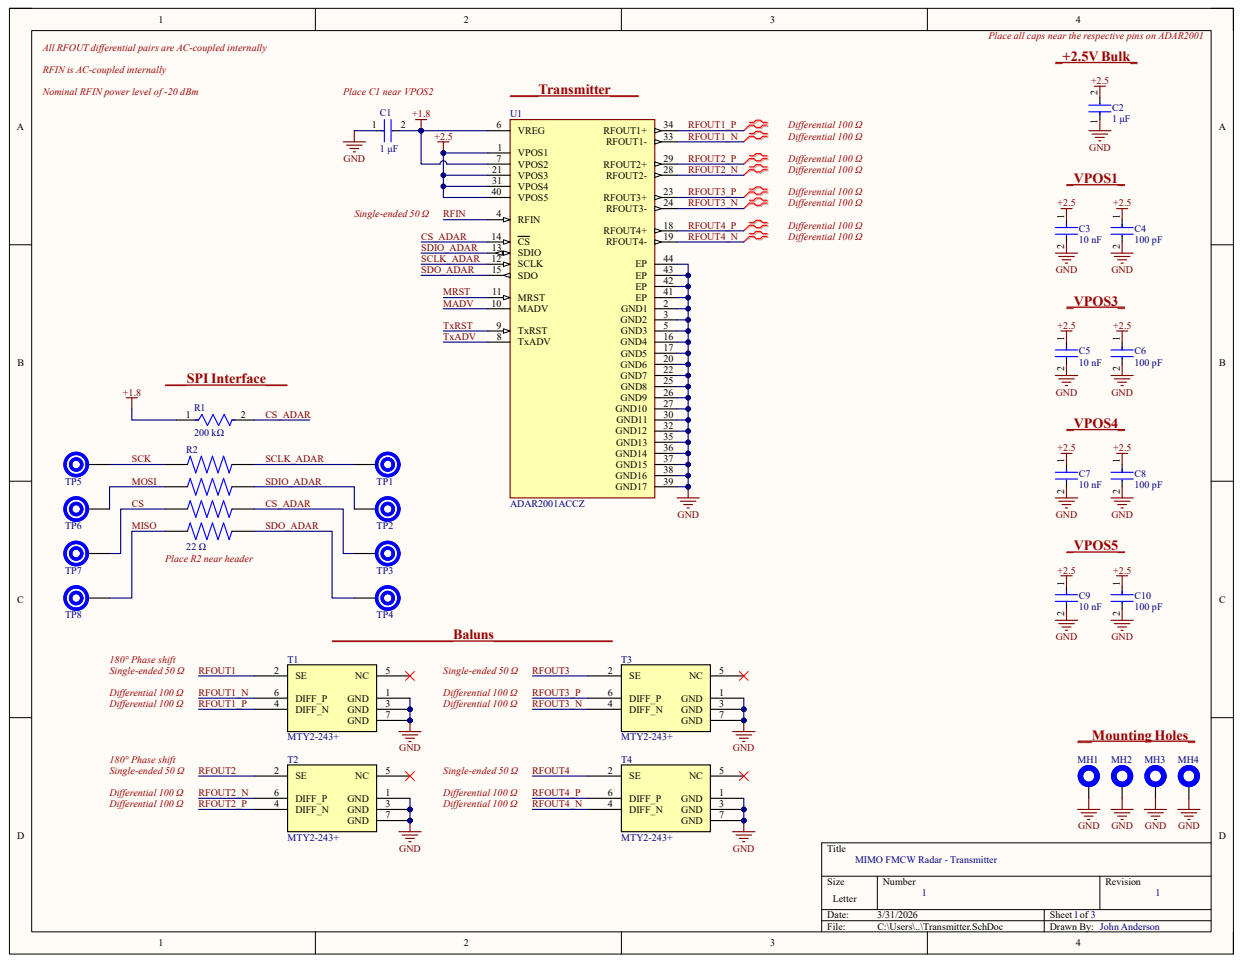
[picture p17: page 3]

Place all caps near the respective pins on ADAR2001

All RFOUT differential pairs are AC-coupled internally

RFIN is AC-coupled internally

Nominal RFIN power level of -20 dBm

Title
MIMO FMCW Radar - Transmitter

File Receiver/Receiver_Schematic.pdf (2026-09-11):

## ______IF Outputs______

# VLogic 1 2

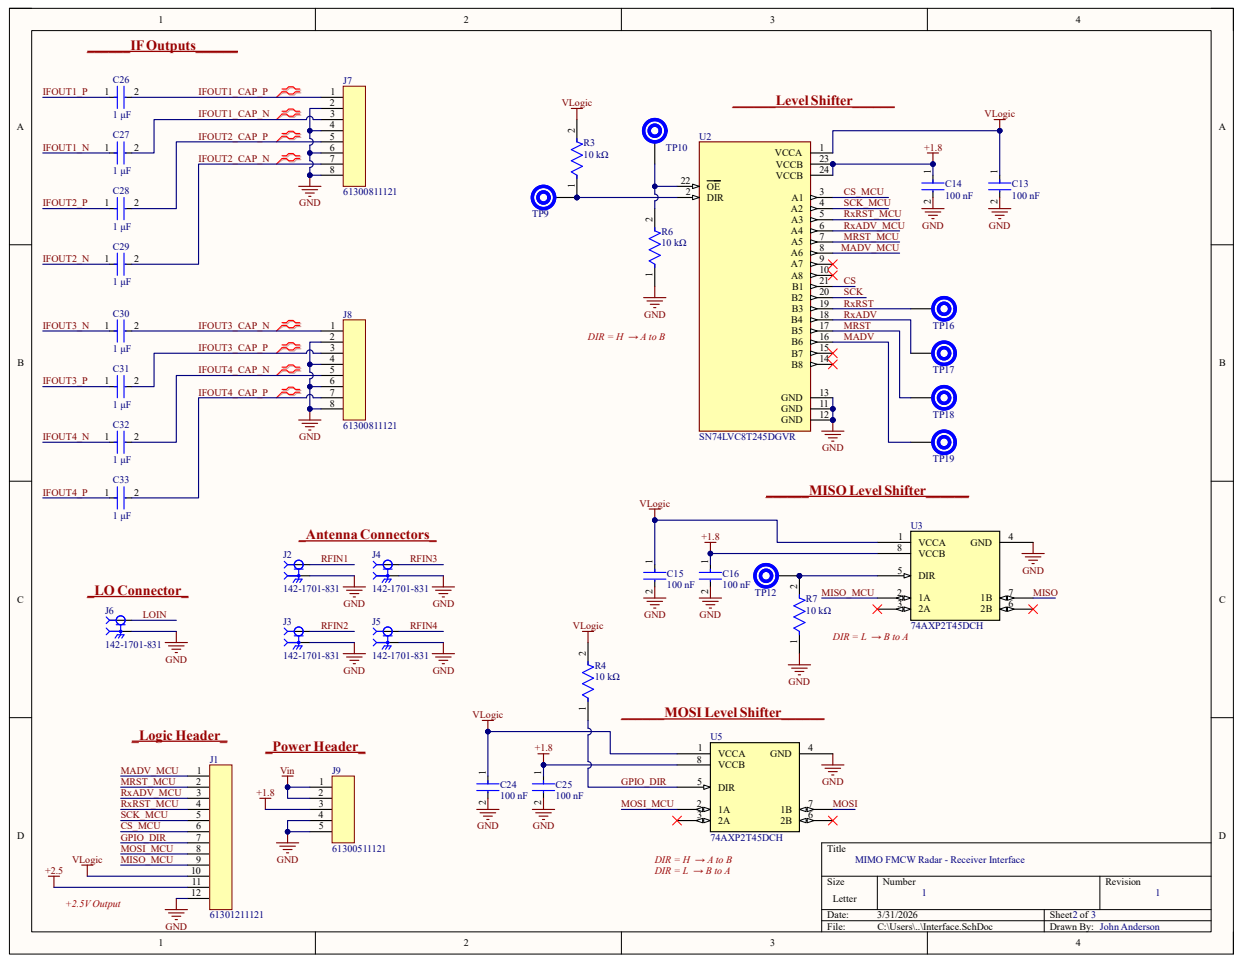
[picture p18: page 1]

Title
MIMO FMCW Radar - Receiver Interface

## _+1.8 Filtering_

## _VLogic Filtering_

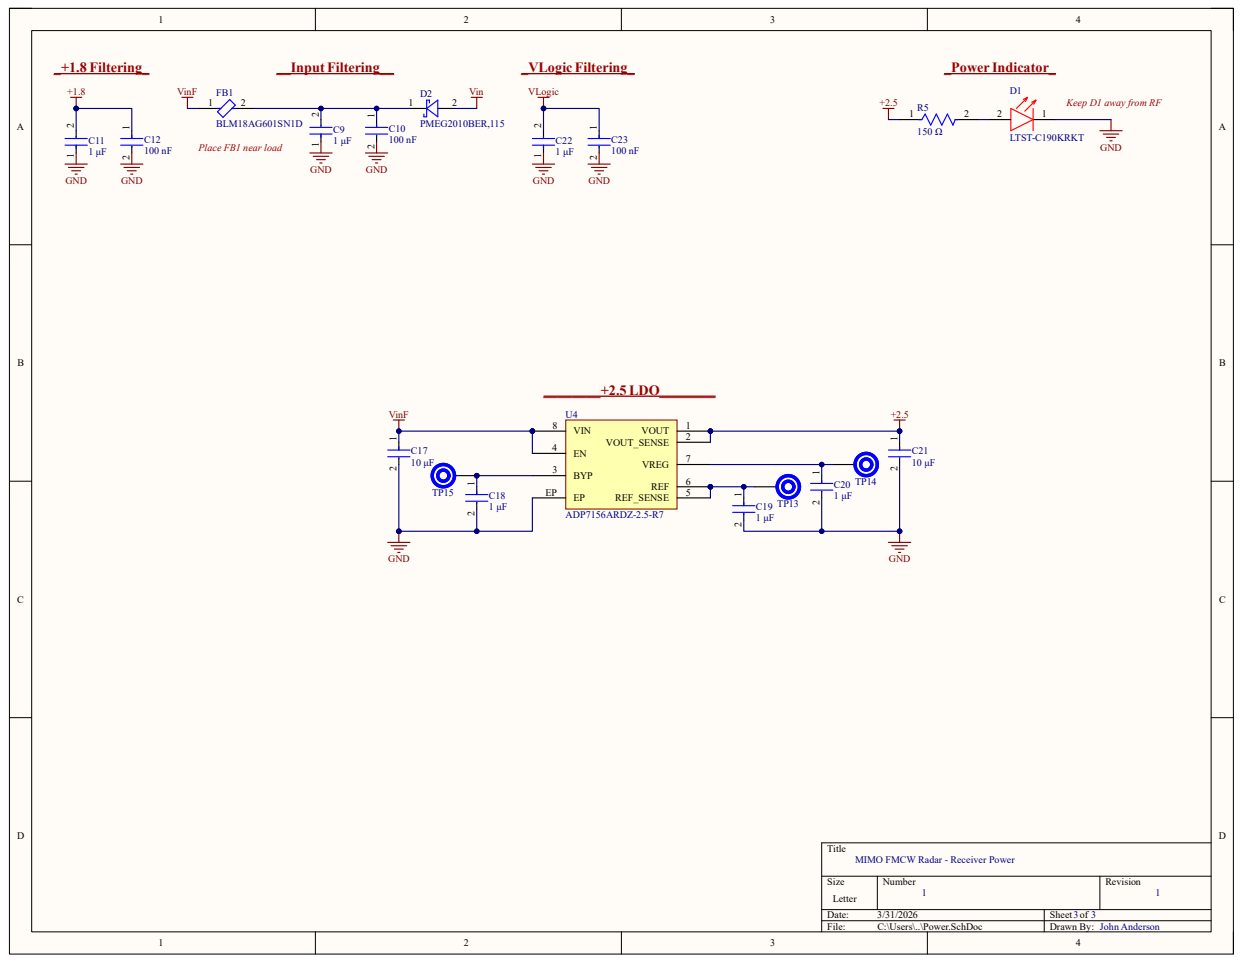
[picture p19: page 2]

Keep D1 away from RF

Title
MIMO FMCW Radar - Receiver Power

## _____Receiver____ _+2.5V Bulk_

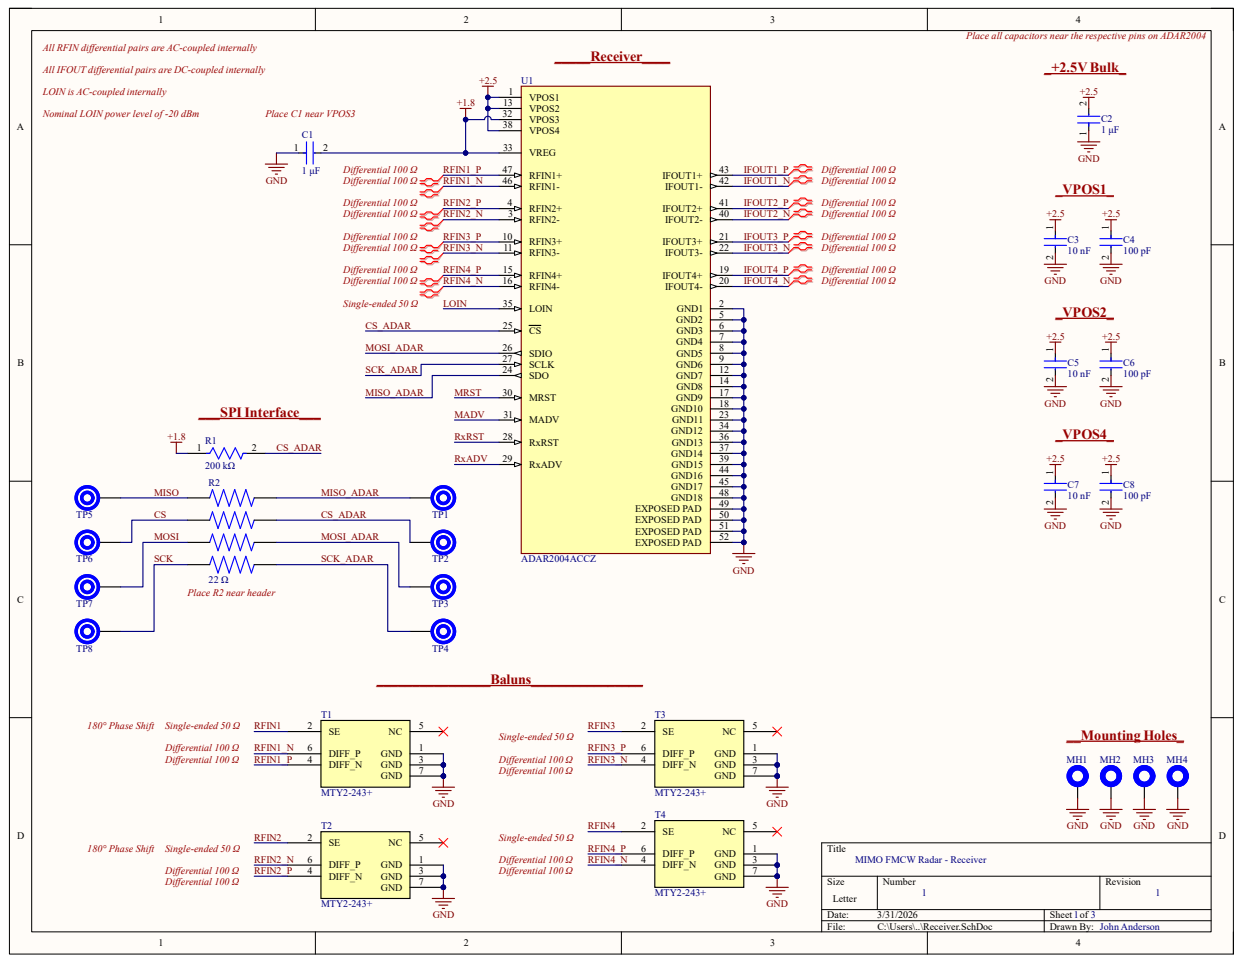
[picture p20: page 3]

Place all capacitors near the respective pins on ADAR2004

All RFIN differential pairs are AC-coupled internally

All IFOUT differential pairs are DC-coupled internally

LOIN is AC-coupled internally

Nominal LOIN power level of -20 dBm

Title
MIMO FMCW Radar - Receiver

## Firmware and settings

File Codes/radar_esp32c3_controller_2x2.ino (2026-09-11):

/*
 * FMCW MIMO RADAR — ESP32-C3 SPI & State Machine Controller
 * =================================================================
 * 1:1 port of the bench-validated Arduino Uno firmware to
 * ESP32-C3-DevKitC-02 v1.1. Behavior on the wire is byte-for-byte
 * identical: same 24-bit SPI framing, same R/W flag bit, same pulse
 * widths and inter-pulse timings, same register init sequence, same
 * scratchpad verify, same MIMO frame pattern.
 *
 * Differences from the Arduino version are limited to platform glue:
 *   - ESP32-C3 GPIO numbers instead of Uno digital pins
 *   - SPI.begin(SCK, MISO, MOSI, -1) explicit-pin form (FSPI bus)
 *   - delay(200) at boot in place of while(!Serial)
 *   - PIN_GPIO_DIR driven HIGH (new PCB uses 74AXP2T45 level shifters
 *     that require a DIR signal; the old TXB0108 setup did not)
 *
 * Hardware: ESP32-C3-DevKitC-02 v1.1 + Transmitter PCB (ADAR2001 +
 *           ADP7156 LDO + SN74LVC8T245 + 2x 74AXP2T45 level shifters)
 * SPI:      24-bit frame: [R/W(1)][ADDR(15)][DATA(8)], Mode 0,
 *           MSB first, 4 MHz on FSPI bus
 * Serial:   115200 baud over USB-UART (default UART0 = GPIO 20/21)
 *
 * SYNCHRONIZATION: Software sync (MATLAB orchestrates)
 *   MATLAB sends command -> ESP32-C3 executes -> "OK" -> MATLAB proceeds
 *   No hardware trigger wire needed.
 *
 * PIN MAPPING (ESP32-C3 -> PCB J1 logic header):
 *   GPIO  6 = SCK  (FSPI)         -> ADAR SCLK   (J1 pin 6)
 *   GPIO  7 = MOSI (FSPI)         -> ADAR SDIO   (J1 pin 7)
 *   GPIO  5 = MISO (FSPI)         <- ADAR SDO    (J1 pin 8)
 *   GPIO  4 = CS_TX               -> ADAR2001 CS (J1 pin 5)
 *   GPIO  8 = CS_RX               -> (TX-only board: not connected;
 *                                     this is also the onboard LED pin
 *                                     and a strapping pin, but stays
 *                                     HIGH the whole time so neither
 *                                     bothers anything)
 *   GPIO  0 = TxADV               -> ADAR2001 TxADV (J1 pin 1)
 *   GPIO  1 = TxRST               -> ADAR2001 TxRST (J1 pin 2)
 *   GPIO  3 = MADV                -> ADAR2001 MADV  (J1 pin 3)
 *   GPIO 10 = MRST                -> ADAR2001 MRST  (J1 pin 4)
 *   GPIO 18 = GPIO_DIR            -> 74AXP2T45 DIR  (J1 pin 9)
 *
 * AVOIDED PINS (ESP32-C3 specific):
 *   GPIO 11-17: reserved for internal SPI flash
 *   GPIO 20, 21: UART0 RX/TX (USB-UART for the serial monitor)
 *   GPIO 2, 9: strapping pins (boot-mode select, BOOT button) — left
 *              as inputs with their default pullups
 *
 * GPIO 18 and 19 are technically the C3's native USB D-/D+, but on
 * the DevKitC-02 v1.1 the USB connector is wired to the external
 * USB-UART chip (not the native USB), so these are free as GPIOs.
 *
 * POWER:
 *   PSU CH1 +5 V    -> J7 pin 1 (Vin), 500 mA limit
 *   PSU CH1 GND     -> J7 pin 3 (GND)
 *   ESP32-C3 3V3    -> J1 pin 10 (VLogic)
 *   ESP32-C3 GND    -> J1 pin 12 (GND)
 *
 * SERIAL COMMANDS (terminated by '\n'):
 *   I         — Init both ICs (full register programming)
 *   V         — Verify SPI (scratch-pad write -> readback -> compare)
 *   S         — Enable sequencers (hardware-pulse mode)
 *   D         — Disable sequencers (SPI-direct mode)
 *   P         — Pulse TxADV (advance TX channel, 50us settle included)
 *   R         — Reset state machines (MRST + TxRST)
 *   M         — Pulse MADV
 *   C N       — Set TX channel directly via SPI (1-4)
 *   W AAA DD  — Raw write to TX
 *   w AAA DD  — Raw write to RX
 *   X AAA     — Raw read from TX
 *   x AAA     — Raw read from RX
 *   ?         — Help
 */

#include <SPI.h>

// ===================== PIN DEFINITIONS =====================
// FSPI bus pins
#define PIN_SCK        6
#define PIN_MISO       5
#define PIN_MOSI       7

// CS lines
#define PIN_CS_TX      4
#define PIN_CS_RX      8

// State-machine control pins
#define PIN_TxADV      0
#define PIN_TxRST      1
#define PIN_MADV       3
#define PIN_MRST      10

// Level-shifter direction control
#define PIN_GPIO_DIR  18

#define SPI_SPEED  4000000
#define MULT_EN_16_20    0x6E
#define MULT_PASS_16_20  0x9F

// ===================== ACTIVE CHANNEL CONFIG =====================
// Which TX/RX channels are physically working. For 2x2 MIMO with damaged
// TX2/TX3 baluns and RFIN2/RFIN3 antennas, use {1, 4} for both.
// When all antennas are repaired, change to {1, 2, 3, 4}.
//
// This array drives:
//   - State-machine mode programming (initADAR2001)
//   - RX channel enable mask (initADAR2004)
//   - 'C N' command channel masks (setChannelDirect)
static const uint8_t TX_CHANNELS[] = {1, 4};
static const uint8_t RX_CHANNELS[] = {1, 4};
static const uint8_t NUM_TX_ACTIVE = sizeof(TX_CHANNELS) / sizeof(TX_CHANNELS[0]);
static const uint8_t NUM_RX_ACTIVE = sizeof(RX_CHANNELS) / sizeof(RX_CHANNELS[0]);

// TX channel masks for register 0x045 (TX_EN1_SPI). Index = channel - 1.
static const uint8_t TX_CH_MASK[4] = {0xC0, 0x30, 0x0C, 0x03};

// Helper: build RX_EN_SPI value (0x02B) from RX_CHANNELS array.
// Bits 7,6,5 = LNA, MIX, IFAMP enable. Bits 3..0 = CH1..CH4.
static uint8_t computeRxEnMask() {
  uint8_t mask = 0xE0;  // LNA + MIX + IFAMP all on
  for (uint8_t i = 0; i < NUM_RX_ACTIVE; i++) {
    uint8_t ch = RX_CHANNELS[i];
    if (ch >= 1 && ch <= 4) mask |= (0x08 >> (ch - 1));   // bit 3 = CH1, bit 2 = CH2, bit 1 = CH3, bit 0 = CH4
  }
  return mask;
}

// Helper: check if a TX channel is in the active set.
static bool isActiveTx(uint8_t ch) {
  for (uint8_t i = 0; i < NUM_TX_ACTIVE; i++) {
    if (TX_CHANNELS[i] == ch) return true;
  }
  return false;
}

// ===================== CORE SPI =====================

void spiWrite(uint8_t csPin, uint16_t addr, uint8_t data) {
  uint8_t b0 = (addr >> 8) & 0x7F;
  uint8_t b1 = addr & 0xFF;
  SPI.beginTransaction(SPISettings(SPI_SPEED, MSBFIRST, SPI_MODE0));
  digitalWrite(csPin, LOW);
  SPI.transfer(b0);
  SPI.transfer(b1);
  SPI.transfer(data);
  digitalWrite(csPin, HIGH);
  SPI.endTransaction();
}

uint8_t spiRead(uint8_t csPin, uint16_t addr) {
  uint8_t b0 = 0x80 | ((addr >> 8) & 0x7F);
  uint8_t b1 = addr & 0xFF;
  SPI.beginTransaction(SPISettings(SPI_SPEED, MSBFIRST, SPI_MODE0));
  digitalWrite(csPin, LOW);
  SPI.transfer(b0);
  SPI.transfer(b1);
  uint8_t result = SPI.transfer(0x00);
  digitalWrite(csPin, HIGH);
  SPI.endTransaction();
  return result;
}

// ===================== PULSE HELPERS =====================

void pulseTxADV() {
  digitalWrite(PIN_TxADV, HIGH);
  delayMicroseconds(1);
  digitalWrite(PIN_TxADV, LOW);
  delayMicroseconds(50);
}

void pulseTxRST() {
  digitalWrite(PIN_TxRST, HIGH);
  delayMicroseconds(1);
  digitalWrite(PIN_TxRST, LOW);
}

void pulseMADV() {
  digitalWrite(PIN_MADV, HIGH);
  delayMicroseconds(1);
  digitalWrite(PIN_MADV, LOW);
  delayMicroseconds(100);
}

void pulseMRST() {
  digitalWrite(PIN_MRST, HIGH);
  delayMicroseconds(1);
  digitalWrite(PIN_MRST, LOW);
}

// ===================== IC INIT =====================

bool verifySPI() {
  Serial.println(F("--- SPI Verification ---"));
  spiWrite(PIN_CS_TX, 0x00A, 0xA5);
  delay(1);
  uint8_t rd_tx = spiRead(PIN_CS_TX, 0x00A);
  bool tx_ok = (rd_tx == 0xA5);
  Serial.print(F("  TX: wrote 0xA5, read 0x")); Serial.print(rd_tx, HEX);
  Serial.println(tx_ok ? F(" PASS") : F(" FAIL"));

  spiWrite(PIN_CS_RX, 0x00A, 0x5A);
  delay(1);
  uint8_t rd_rx = spiRead(PIN_CS_RX, 0x00A);
  bool rx_ok = (rd_rx == 0x5A);
  Serial.print(F("  RX: wrote 0x5A, read 0x")); Serial.print(rd_rx, HEX);
  Serial.println(rx_ok ? F(" PASS") : F(" FAIL"));

  return tx_ok && rx_ok;
}

void initADAR2001() {
  Serial.println(F("--- Init ADAR2001 (TX) ---"));
  spiWrite(PIN_CS_TX, 0x000, 0x81); delay(10);
  spiWrite(PIN_CS_TX, 0x000, 0x18);
  spiWrite(PIN_CS_TX, 0x010, 0x01);
  spiWrite(PIN_CS_TX, 0x011, 0xBB);
  spiWrite(PIN_CS_TX, 0x012, 0x0B);
  spiWrite(PIN_CS_TX, 0x013, 0x75);
  spiWrite(PIN_CS_TX, 0x014, 0xB5);
  spiWrite(PIN_CS_TX, 0x015, 0x0C);
  spiWrite(PIN_CS_TX, 0x016, 0x10);
  spiWrite(PIN_CS_TX, 0x018, 0x10);
  spiWrite(PIN_CS_TX, 0x047, MULT_EN_16_20);
  spiWrite(PIN_CS_TX, 0x048, MULT_PASS_16_20);
  spiWrite(PIN_CS_TX, 0x045, 0xC0);
  spiWrite(PIN_CS_TX, 0x046, 0x07);
  // Mult modes
  spiWrite(PIN_CS_TX, 0x070, 0x00); spiWrite(PIN_CS_TX, 0x071, 0x00);
  spiWrite(PIN_CS_TX, 0x072, MULT_EN_16_20); spiWrite(PIN_CS_TX, 0x073, MULT_PASS_16_20);
  // TX modes — driven by TX_CHANNELS config at top of file.
  // Mode 0 = sleep. Modes 1..NUM_TX_ACTIVE are taken from TX_CHANNELS in order.
  // For 2-TX MIMO with TX_CHANNELS={1,4}: mode 1=TX1, mode 2=TX4 (states 3,4 unused).
  spiWrite(PIN_CS_TX, 0x050, 0x00); spiWrite(PIN_CS_TX, 0x051, 0x00);  // mode 0: sleep
  for (uint8_t i = 0; i < 4; i++) {
    uint16_t addr = 0x052 + i * 2;
    if (i < NUM_TX_ACTIVE) {
      spiWrite(PIN_CS_TX, addr,     TX_CH_MASK[TX_CHANNELS[i] - 1]);
      spiWrite(PIN_CS_TX, addr + 1, 0x07);
    } else {
      // Unused mode — leave as sleep (no PA active)
      spiWrite(PIN_CS_TX, addr,     0x00);
      spiWrite(PIN_CS_TX, addr + 1, 0x00);
    }
  }
  // State assignments — sequencer always cycles 0->1->2->3->4 mapped to modes 1,2,3,4.
  // Number of TxADV pulses per frame is controlled by NUM_TX_ACTIVE (in MATLAB or hw_trig).
  spiWrite(PIN_CS_TX, 0x03C, 0x10);
  spiWrite(PIN_CS_TX, 0x019, 0x12);
  spiWrite(PIN_CS_TX, 0x01A, 0x34);
  Serial.println(F("  Done."));
}

void initADAR2004() {
  Serial.println(F("--- Init ADAR2004 (RX) ---"));
  spiWrite(PIN_CS_RX, 0x000, 0x81); delay(10);
  spiWrite(PIN_CS_RX, 0x000, 0x18);
  spiWrite(PIN_CS_RX, 0x010, 0x01);
  spiWrite(PIN_CS_RX, 0x011, 0x55);
  spiWrite(PIN_CS_RX, 0x012, 0x07);
  spiWrite(PIN_CS_RX, 0x013, 0x78);
  spiWrite(PIN_CS_RX, 0x014, 0x7A);
  spiWrite(PIN_CS_RX, 0x015, 0x2A);
  spiWrite(PIN_CS_RX, 0x016, 0xC0);
  spiWrite(PIN_CS_RX, 0x017, 0x04);
  spiWrite(PIN_CS_RX, 0x018, 0x00);
  spiWrite(PIN_CS_RX, 0x019, 0x00);
  spiWrite(PIN_CS_RX, 0x02F, 0xEE);
  spiWrite(PIN_CS_RX, 0x02B, computeRxEnMask());
  spiWrite(PIN_CS_RX, 0x02E, 0x07);
  spiWrite(PIN_CS_RX, 0x02C, 0x77);
  spiWrite(PIN_CS_RX, 0x02D, 0x77);
  Serial.println(F("  Done."));
}

void enableSequencers() {
  spiWrite(PIN_CS_TX, 0x018, 0x90);
  spiWrite(PIN_CS_TX, 0x016, 0x90);
  spiWrite(PIN_CS_TX, 0x017, 0x03);
}

void disableSequencers() {
  spiWrite(PIN_CS_TX, 0x016, 0x10);
  spiWrite(PIN_CS_TX, 0x018, 0x10);
}

void setChannelDirect(uint8_t ch) {
  if (!isActiveTx(ch)) {
    Serial.print(F("WARN: TX")); Serial.print(ch);
    Serial.println(F(" not in active set, switching anyway"));
  }
  uint8_t val;
  switch (ch) {
    case 1: val = 0xC0; break; case 2: val = 0x30; break;
    case 3: val = 0x0C; break; case 4: val = 0x03; break;
    default: val = 0x00; break;
  }
  spiWrite(PIN_CS_TX, 0x045, val);
  spiWrite(PIN_CS_TX, 0x046, 0x07);
}

// ===================== SERIAL HANDLER =====================

void processCommand() {
  String cmd = Serial.readStringUntil('\n');
  cmd.trim();
  if (cmd.length() == 0) return;
  char c = cmd.charAt(0);

  switch (c) {
    case 'I':
      initADAR2001(); initADAR2004();
      Serial.println(F("OK INIT"));
      break;
    case 'V':
      Serial.println(verifySPI() ? F("OK VERIFY") : F("FAIL VERIFY"));
      break;
    case 'S':
      enableSequencers();
      Serial.println(F("OK SEQ_ON"));
      break;
    case 'D':
      disableSequencers();
      Serial.println(F("OK SEQ_OFF"));
      break;
    case 'P':
      pulseTxADV();
      Serial.println(F("OK TxADV"));
      break;
    case 'R':
      pulseMRST(); pulseTxRST(); delayMicroseconds(10);
      Serial.println(F("OK RESET"));
      break;
    case 'M':
      pulseMADV();
      Serial.println(F("OK MADV"));
      break;
    case 'C': {
      uint8_t ch = cmd.substring(2).toInt();
      if (ch >= 1 && ch <= 4) {
        setChannelDirect(ch);
        Serial.print(F("OK CH")); Serial.println(ch);
      } else Serial.println(F("ERR CH 1-4"));
      break;
    }
    case 'W': {
      uint16_t a = strtol(cmd.substring(2,5).c_str(), NULL, 16);
      uint8_t  d = strtol(cmd.substring(6,8).c_str(), NULL, 16);
      spiWrite(PIN_CS_TX, a, d);
      Serial.print(F("OK WR_TX 0x")); Serial.print(a,HEX);
      Serial.print(F("=0x")); Serial.println(d,HEX);
      break;
    }
    case 'w': {
      uint16_t a = strtol(cmd.substring(2,5).c_str(), NULL, 16);
      uint8_t  d = strtol(cmd.substring(6,8).c_str(), NULL, 16);
      spiWrite(PIN_CS_RX, a, d);
      Serial.print(F("OK WR_RX 0x")); Serial.print(a,HEX);
      Serial.print(F("=0x")); Serial.println(d,HEX);
      break;
    }
    case 'X': {
      uint16_t a = strtol(cmd.substring(2,5).c_str(), NULL, 16);
      uint8_t  v = spiRead(PIN_CS_TX, a);
      Serial.print(F("OK RD_TX 0x")); Serial.print(a,HEX);
      Serial.print(F("=0x")); Serial.println(v,HEX);
      break;
    }
    case 'x': {
      uint16_t a = strtol(cmd.substring(2,5).c_str(), NULL, 16);
      uint8_t  v = spiRead(PIN_CS_RX, a);
      Serial.print(F("OK RD_RX 0x")); Serial.print(a,HEX);
      Serial.print(F("=0x")); Serial.println(v,HEX);
      break;
    }
    case '?':
      Serial.println(F("=== FMCW MIMO Radar Controller ==="));
      Serial.println(F("I=Init V=Verify S=SeqOn D=SeqOff"));
      Serial.println(F("P=TxADV R=Reset M=MADV C N=SetCh"));
      Serial.println(F("W AAA DD=WriteTX w AAA DD=WriteRX"));
      Serial.println(F("X AAA=ReadTX x AAA=ReadRX"));
      Serial.println(F("MIMO: R->M->P,cap->P,cap->P,cap->P,cap"));
      break;
    default:
      Serial.print(F("ERR: ")); Serial.println(cmd);
      break;
  }
}

void setup() {
  Serial.begin(115200);
  delay(200);
  pinMode(PIN_CS_TX, OUTPUT); pinMode(PIN_CS_RX, OUTPUT);
  pinMode(PIN_TxADV, OUTPUT); pinMode(PIN_TxRST, OUTPUT);
  pinMode(PIN_MADV, OUTPUT);  pinMode(PIN_MRST, OUTPUT);
  pinMode(PIN_GPIO_DIR, OUTPUT);
  digitalWrite(PIN_CS_TX, HIGH); digitalWrite(PIN_CS_RX, HIGH);
  digitalWrite(PIN_TxADV, LOW);  digitalWrite(PIN_TxRST, LOW);
  digitalWrite(PIN_MADV, LOW);   digitalWrite(PIN_MRST, LOW);
  digitalWrite(PIN_GPIO_DIR, HIGH);
  SPI.begin(PIN_SCK, PIN_MISO, PIN_MOSI, -1);
  Serial.println(F(""));
  Serial.println(F("=== FMCW MIMO Radar Ready (ESP32-C3) ==="));
  Serial.println(F("HW SPI 4MHz, 24-bit, Mode 0"));
  Serial.print(F("Active TX: ["));
  for (uint8_t i = 0; i < NUM_TX_ACTIVE; i++) {
    Serial.print(TX_CHANNELS[i]); if (i < NUM_TX_ACTIVE - 1) Serial.print(F(","));
  }
  Serial.print(F("]  Active RX: ["));
  for (uint8_t i = 0; i < NUM_RX_ACTIVE; i++) {
    Serial.print(RX_CHANNELS[i]); if (i < NUM_RX_ACTIVE - 1) Serial.print(F(","));
  }
  Serial.println(F("]"));
  Serial.println(F("Software sync — send ? for help"));
}

void loop() {
  if (Serial.available()) processCommand();
}

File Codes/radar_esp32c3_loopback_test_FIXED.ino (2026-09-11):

/*
 * Radar TX-as-Source Loopback Test (ESP32-C3)
 * =================================================================
 * Combined TX + RX bench test that uses the TX board's 18 GHz output
 * as the RF input to the RX board. Eliminates the need for a 20 GHz
 * signal generator — only two 4.5 GHz sources (SG396) needed.
 *
 * SIGNAL FLOW:
 *   SG396 #1 (4.500000 GHz, -20 dBm) -> TX J6 -> 4x mult -> 18.000 GHz
 *     out at TX J2 -> 20 dB pad -> RX J2 (RFIN1) -> mixer
 *   SG396 #2 (4.500250 GHz, -20 dBm) -> RX J6 -> 4x mult -> 18.001 GHz
 *     internal LO -> mixer
 *   IF = |18.001 GHz - 18.000 GHz| = 1 MHz at RX J7 IFOUT1+/-
 *
 * Both chips configured in SPI-direct mode for the mid-band 16-20 GHz
 * multiplier path, single channel active each side (TX1 and RX1).
 *
 * This firmware programs both chips in a single auto-init at boot.
 * Behavior on the SPI wire is byte-for-byte identical to the
 * validated initADAR2001() and initADAR2004() routines in
 * radar_arduino_controller.ino.
 *
 * PIN MAPPING (ESP32-C3 -> shared between TX J1 and RX J1):
 *
 *   ESP32 GPIO   Signal           TX J1 pin   RX J1 pin
 *   ----------   --------------   ---------   ---------
 *   GPIO  0      TxADV/RxADV          1           3
 *   GPIO  1      TxRST/RxRST          2           4
 *   GPIO  3      MADV (shared)        3           1
 *   GPIO 10      MRST (shared)        4           2
 *   GPIO  6      SCK  (shared)        6           5
 *   GPIO  7      MOSI (shared)        7           8
 *   GPIO  5      MISO (shared)        8           9
 *   GPIO 18      GPIO_DIR (shared)    9           7
 *   GPIO  4      CS_TX                5          (n/c)
 *   GPIO  8      CS_RX               (n/c)        6
 *   3V3 pin      VLogic              10          10
 *   GND pin      GND                 12          12
 *
 * Eight signals fan out from one ESP32 GPIO to both J1 headers
 * (use a breadboard rail). Two unique signals (CS_TX, CS_RX) go to
 * one J1 only. Power: PSU 5V in parallel to TX J7 and RX J9 Vin
 * pins; PSU GND in parallel to both ground pins.
 *
 * RF cabling:
 *   SG396 #1 -> TX J6 (LO for TX side)
 *   SG396 #2 -> RX J6 (LO for RX side, set 250 kHz higher than #1)
 *   TX J2 -> 20 dB SMA pad -> RX J2 (RF feed)
 *   RX J7 pin 1 (IFOUT1_P) -> USB-6366 AI 0 BNC center
 *   RX J7 pin 2 or 8 (GND) -> USB-6366 AI 0 BNC shell
 *   USB-6366 AI 0 FS/GS switch: GS (single-ended, simplest)
 *
 * Serial commands (115200 baud):
 *   I    - Re-run full init for both chips
 *   V    - SPI verify on both TX and RX
 *   R    - Read back current TX and RX register state
 *   t N  - Set TX channel (1-4): N=1 -> J2, N=2 -> J3, etc.
 *   r N  - Set RX channel (1-4): N=1 -> J2, N=2 -> J3, etc.
 *   ?    - Help
 */

#include <SPI.h>

// FSPI bus
#define PIN_SCK        6
#define PIN_MISO       5
#define PIN_MOSI       7

// CS lines
#define PIN_CS_TX      4
#define PIN_CS_RX      8

// State-machine pins (unused in SPI-direct, but kept LOW for safety)
#define PIN_TxADV_RxADV  0
#define PIN_TxRST_RxRST  1
#define PIN_MADV         3
#define PIN_MRST        10

// Level-shifter direction control
#define PIN_GPIO_DIR    18

#define SPI_SPEED        4000000

// =============== SPI ===============

void spiWrite(uint8_t csPin, uint16_t addr, uint8_t data) {
  uint8_t b0 = (addr >> 8) & 0x7F;
  uint8_t b1 = addr & 0xFF;
  SPI.beginTransaction(SPISettings(SPI_SPEED, MSBFIRST, SPI_MODE0));
  digitalWrite(csPin, LOW);
  SPI.transfer(b0); SPI.transfer(b1); SPI.transfer(data);
  digitalWrite(csPin, HIGH);
  SPI.endTransaction();
}

uint8_t spiRead(uint8_t csPin, uint16_t addr) {
  uint8_t b0 = 0x80 | ((addr >> 8) & 0x7F);
  uint8_t b1 = addr & 0xFF;
  SPI.beginTransaction(SPISettings(SPI_SPEED, MSBFIRST, SPI_MODE0));
  digitalWrite(csPin, LOW);
  SPI.transfer(b0); SPI.transfer(b1);
  uint8_t r = SPI.transfer(0x00);
  digitalWrite(csPin, HIGH);
  SPI.endTransaction();
  return r;
}

// =============== Verify ===============

bool verifySPI() {
  Serial.println(F("--- SPI Verification ---"));
  spiWrite(PIN_CS_TX, 0x00A, 0xA5); delay(1);
  uint8_t rt = spiRead(PIN_CS_TX, 0x00A);
  bool tx_ok = (rt == 0xA5);
  Serial.print(F("  TX: wrote 0xA5, read 0x")); Serial.print(rt, HEX);
  Serial.println(tx_ok ? F(" PASS") : F(" FAIL"));

  spiWrite(PIN_CS_RX, 0x00A, 0x5A); delay(1);
  uint8_t rr = spiRead(PIN_CS_RX, 0x00A);
  bool rx_ok = (rr == 0x5A);
  Serial.print(F("  RX: wrote 0x5A, read 0x")); Serial.print(rr, HEX);
  Serial.println(rx_ok ? F(" PASS") : F(" FAIL"));

  return tx_ok && rx_ok;
}

// =============== Init: TX (ADAR2001, mid-band, TX1 active) ===============

void initTX() {
  Serial.println(F("--- Init TX (ADAR2001, SPI-direct, TX1 active) ---"));
  spiWrite(PIN_CS_TX, 0x000, 0x81); delay(10);
  spiWrite(PIN_CS_TX, 0x000, 0x18);
  spiWrite(PIN_CS_TX, 0x010, 0x01);
  // Bias (ADAR2001 datasheet defaults)
  spiWrite(PIN_CS_TX, 0x011, 0xBB);
  spiWrite(PIN_CS_TX, 0x012, 0x0B);
  spiWrite(PIN_CS_TX, 0x013, 0x75);
  spiWrite(PIN_CS_TX, 0x014, 0xB5);
  spiWrite(PIN_CS_TX, 0x015, 0x0C);
  // Sequencers off, latch bypass on
  spiWrite(PIN_CS_TX, 0x016, 0x10);
  spiWrite(PIN_CS_TX, 0x018, 0x10);
  // Multiplier mid-band 16-20 GHz
  spiWrite(PIN_CS_TX, 0x047, 0x6E);
  spiWrite(PIN_CS_TX, 0x048, 0x9F);
  // TX1 active, splitters all on
  spiWrite(PIN_CS_TX, 0x045, 0xC0);
  spiWrite(PIN_CS_TX, 0x046, 0x07);
  Serial.println(F("  TX1 active. Expect 18 GHz at J2 (~-3 dBm)."));
}

// =============== Init: RX (ADAR2004, mid-band, RX1 active) ===============

void initRX() {
  Serial.println(F("--- Init RX (ADAR2004, SPI-direct, RX1 active) ---"));
  spiWrite(PIN_CS_RX, 0x000, 0x81); delay(10);
  spiWrite(PIN_CS_RX, 0x000, 0x18);
  spiWrite(PIN_CS_RX, 0x010, 0x01);
  // Bias (ADAR2004 datasheet defaults — DIFFERENT from ADAR2001)
  spiWrite(PIN_CS_RX, 0x011, 0x55);
  spiWrite(PIN_CS_RX, 0x012, 0x07);
  spiWrite(PIN_CS_RX, 0x013, 0x78);
  spiWrite(PIN_CS_RX, 0x014, 0x7A);
  spiWrite(PIN_CS_RX, 0x015, 0x2A);
  spiWrite(PIN_CS_RX, 0x016, 0xC0);
  spiWrite(PIN_CS_RX, 0x017, 0x04);
  // Sequencers off
  spiWrite(PIN_CS_RX, 0x018, 0x00);
  spiWrite(PIN_CS_RX, 0x019, 0x00);
  // Multiplier mid-band 16-20 GHz
  spiWrite(PIN_CS_RX, 0x02F, 0xEE);
  // Splitters all on
  spiWrite(PIN_CS_RX, 0x02E, 0x07);
  // Gains all max
  spiWrite(PIN_CS_RX, 0x02C, 0x77);
  spiWrite(PIN_CS_RX, 0x02D, 0x77);
  // RX1 active: LNA + MIX + IFAMP + CH1
  spiWrite(PIN_CS_RX, 0x02B, 0xE8);
  Serial.println(F("  RX1 active. Expect 1 MHz IF at J7 IFOUT1+/-."));
}

// =============== Channel switching ===============
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
